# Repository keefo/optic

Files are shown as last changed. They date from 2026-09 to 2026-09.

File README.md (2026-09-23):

# Project Optic

Optic is an ultra-reliable, long-term timelapse system engineered around the Raspberry Pi 5 (1GB) and Raspberry Pi High Quality Camera, fitted with an official 6mm f/1.2 CS-mount wide-angle lens (PT361060M3MP12). Running on a stripped-down, headless Raspberry Pi OS Lite environment, Optic is architected for 365 days of unattended operation—pairing minimal memory overhead with a planned read-only root (OverlayFS, Phase 9; not yet enabled, see `docs/phase9-readonly-root.md`) to prevent file corruption across year-long captures.

## Specifications

### Compute & System
* **Host Platform:** Raspberry Pi 5
* **CPU:** Broadcom BCM2712 (Quad-core Arm Cortex-A76 @ 2.4GHz)
* **Memory:** 1 GB LPDDR4X-4267 SDRAM
* **Operating System:** Raspberry Pi OS Lite (64-bit, Debian base, headless)
* **Filesystem Architecture:** Writable ext4 root today, with RAM-backed `/mnt/capture` for capture staging; read-only OverlayFS root is planned (Phase 9, `docs/phase9-readonly-root.md`)

### Imaging & Optics
* **Sensor:** Raspberry Pi High Quality Camera (Sony IMX477)
* **Native Resolution:** 12.3 Megapixels (4056 × 3040 px)
* **Sensor Format:** 1/2.3" (7.9 mm diagonal, 1.55 µm × 1.55 µm pixel size)
* **Lens Mount:** CS-mount (with integrated back-focus adjustment ring)
* **Lens Model:** Official Raspberry Pi 6mm CS-Mount (`PT361060M3MP12` / `SC0124`)
* **Focal Length & Aperture:** 6.0 mm, adjustable f/1.2 – f/16
* **Field of View (FoV):** ~63° (horizontal)

### Enclosure
* **Design:** 3D-printable four-part outdoor box (base, lid, lens back, lens cover) — CAD source and print notes in [`case/`](case/README.md)
* **Format:** STEP AP214 assembly (`case/pi5/step/pi-cam-case-assembly.step`), editable in Fusion, FreeCAD, Onshape and other CAD tools
* **Licence:** CERN-OHL-S v2 (hardware design only; see `case/LICENSE-hardware.txt`)

### Networking & Access
* **Hostname:** `optic.local`
* **Remote Access:** OpenSSH (key-based authentication recommended)
* **Service Discovery:** mDNS / Avahi zero-configuration networking
* **Camera Dashboard:** [http://optic.local:8000/](http://optic.local:8000/)

## SSH Access

Connect over the local network via:

```bash
ssh liam@optic.local
```

## Hardening Verification

Run the read-only hardening verifier directly on `optic` without installing it:

```bash
cd /Users/admin/Documents/projects/optic
ssh liam@optic.local 'bash -s -- --color' < verify.sh
```

Results use green `PASS`, yellow `WARN`, red `FAIL`, and cyan `INFO` labels. Use `--no-color` for plain output. No settings are changed and no secret values are displayed.

Run one phase at a time with `--phase 1` through `--phase 9`. Phase 7 battery configuration is skipped on this deployment, Phase 8 commissions the HQ Camera, and Phase 9 (OverlayFS) is planned but not yet enabled. Reusable setup scripts are stored in `/Users/admin/Documents/projects/optic/scripts` where automation is appropriate.

## Camera Daemon

`optic-daemon` provides the camera dashboard, IMX477 status, validated camera controls, profile-aware MJPEG previews and test shots, and atomic publication to the Phase 6 RAM stage, plus the timelapse scheduler (`optic_scheduler`), in-process transfer to the iMac (`optic_sync`), capture history, and health alerts. The dashboard preview has browser-side focus tools (histogram, focus peaking, and a loupe with a sharpness score; `docs/optic-daemon-focus-tools.md`). Camera requests enter the bounded FIFO `optic_camera` actor and use one persistent native `libcamera` owner for preview and still capture. Master Archive previews at the full `4056 × 3040` resolution at 2 FPS; 4K DCI and 2K Binning use aspect-correct `1352 × 720` and `1014 × 760` previews at up to 8 FPS. Still captures remain Master Archive (`4056 × 3040`, JPEG Q100 + DNG), 4K DCI (`4056 × 2160`, JPEG Q95 with optional DNG), and 2K Binning (`2028 × 1520`, JPEG Q85). The native backend has been deployed since 0.1.3 (`worklogs/2026-09-16-native-camera-refactor.md`). It runs as the system service `optic-daemon.service` with `User=liam` (`docs/optic-daemon-system-service.md`) and is intentionally exposed on unprivileged TCP port `8000`; nothing listens on port `80`.

```bash
ssh liam@optic.local 'systemctl status optic-daemon.service'
curl http://optic.local:8000/healthz
```

Bootstrap the pinned Pi build environment, upload the current versioned source,
run all validation, build, install, and verify the deployment with one command
from the development Mac:

```bash
cd /Users/admin/Documents/projects/optic
./scripts/build-deploy-optic-daemon.sh
```

See [`optic-daemon.md`](optic-daemon.md) for the deployment procedure, API,
and live-validation record. See
[`optic-daemon-build-environment.md`](optic-daemon-build-environment.md) for
the pinned Raspberry Pi toolchain, native-library sysroot, exact build order,
and failure diagnosis.

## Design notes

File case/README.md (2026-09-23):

# Project Optic enclosure (Raspberry Pi 5 + HQ Camera)

3D-printable outdoor enclosure for the camera station described in the
[project README](../README.md): a Raspberry Pi 5, the Raspberry Pi High
Quality Camera (IMX477) and the 6 mm f/1.2 CS-mount lens
(PT361060M3MP12).

## Files

| Path | What it is |
| --- | --- |
| `pi5/step/pi-cam-case-assembly.step` | **The source model.** STEP AP214, exported from Fusion on 2026-09-22. One assembly holding all four parts as they fit together. Opens and edits in Fusion, FreeCAD, Onshape, SolidWorks and other CAD tools. |

The four parts in the assembly:

1. **Box base** – holds the Pi 5 and the camera module.
2. **Box lid** – closes the base.
3. **Lens back** – the lens mount behind the aperture.
4. **Lens cover** – the front cover over the lens.

> The bodies are unnamed inside the STEP file (the product name is the
> export timestamp), so other CAD tools show them as generic solids.
> Naming the components in Fusion before the next export would carry the
> names across.

### Not here yet

- **Per-part STEP files.** Exporting each component separately
  (right-click the component in the Fusion browser → *Save As STEP*, or
  export with only that component selected) produces one file per part.
  Using *File → Export* instead writes the whole design every time, which
  is why the first attempt produced four identical files.
- **Print-ready meshes** (`.3mf` preferred over `.stl`: it carries units,
  separate parts and print settings). Export each part laid flat in its
  print orientation, not in assembly position.
- **The Fusion source** (`.f3d`), which is the only format that keeps the
  parametric timeline.
- A dimensioned drawing (PDF) and a photo of the assembled box.

The earlier `RaspberryPi5caseV5T-*.stl` files were removed when this STEP
model replaced them: a mesh cannot be edited meaningfully, and those files
were a different design.

## Printing

Material: **ASA** — chosen for UV and heat resistance in a station meant to
run outdoors for a year. It needs an enclosed printer. PETG is a workable
substitute; PLA is not, since it sags in direct sun and goes brittle.

Everything below is still to be filled in from a real print:

| Setting | Value |
| --- | --- |
| Layer height | TBD |
| Wall loops / perimeters | TBD |
| Infill | TBD |
| Supports | TBD |
| Print orientation per part | TBD |
| Estimated print time / filament | TBD |

## Hardware (bill of materials)

TBD — screws, heat-set inserts, fan (the previous design used a 30 mm
fan), gasket or seal, and any lens-mount hardware.

## Assembly

TBD — the order the parts go together, where the cables run, and how the
camera ribbon is routed.

## Licence

The enclosure design in this directory is licensed under the **CERN Open
Hardware Licence Version 2 – Strongly Reciprocal** (`CERN-OHL-S-2.0`); see
[`LICENSE-hardware.txt`](LICENSE-hardware.txt). In short: you may use,
study, modify, make and distribute it, provided you pass on the same
freedoms and publish the source of any modified design you distribute.

This covers the hardware design files only. The software in this
repository is licensed separately.

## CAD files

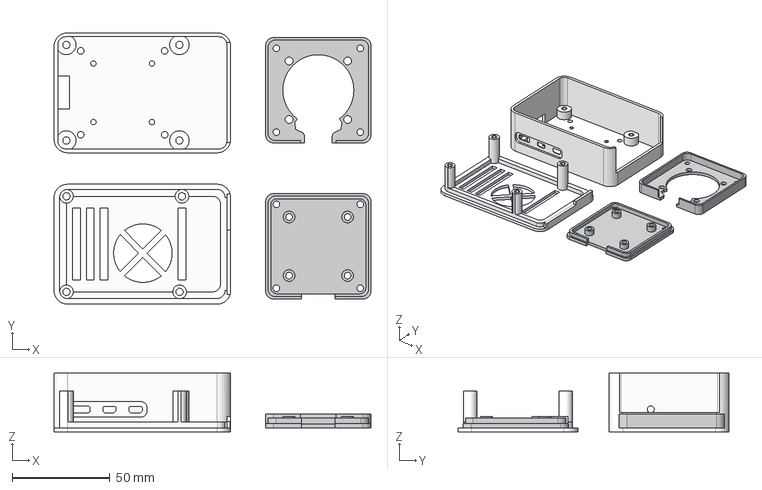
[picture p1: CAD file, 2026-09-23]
case/pi5/step/pi-cam-case-assembly.step
162.5 x 139.1 x 30.0 mm

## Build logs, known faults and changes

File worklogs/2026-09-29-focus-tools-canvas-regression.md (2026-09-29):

# Dated Worklog: 2026-09-29 - Focus Tools Silently Stopped Working After the Canvas Preview

Status: **implemented and locally tested**; Pi `--assets` deploy and user
acceptance pending.

## Objective

User report: Histogram, Peaking, Clipping and Loupe no longer do anything.
The buttons toggle, but nothing is drawn.

## Root Cause

A regression I introduced in PR #19. The iOS flicker fix replaced the
preview `<img id="preview">` with a `<canvas id="preview">`
(`worklogs/2026-09-28-ios-preview-stream.md`). `focus-tools.js` gained
`frameWidth()`/`frameHeight()` helpers for exactly this, and three call
sites were updated — but **`onFrame()` was missed**:

```js
if (!anyEnabled() || !img.naturalWidth || !img.naturalHeight) return;
```

`naturalWidth` is an `<img>` property; a `<canvas>` has `width`/`height`
and no `naturalWidth`. So the guard saw `undefined`, `onFrame()` returned
immediately on every frame, and all four tools did nothing. No error was
logged, because returning early is a legitimate path (it is how a
not-yet-loaded frame is skipped).

Why nothing caught it:

- The JS unit tests only covered the pure functions; the helpers lived
  inside the browser-only half of the file and were never exercised.
- The Rust asset tests pinned the canvas and `createImageBitmap`, not how
  the tools read the frame size.
- `worklogs/2026-09-28-ios-preview-stream.md` explicitly listed "focus tools
  not re-checked on a real device" as a remaining limitation. That gap is
  exactly where the defect sat.

## Fix

- `onFrame()` now reads the size through `frameWidth()`/`frameHeight()`.
- Those helpers moved from the browser-only half into the exported pure
  surface, so Node tests cover them.
- Tests:
  - `tests/web/focus-tools.test.js`: a canvas-shaped object, an image-shaped
    object (intrinsic size beats layout size), and not-ready sources
    returning 0.
  - `src/web.rs`: asserts `onFrame` uses `frameWidth(img)` and that the only
    `.naturalWidth`/`.naturalHeight` reads in the file are the helpers.

## Validation (local, macOS)

| # | Check | Result |
|---|---|---|
| 1 | `node --test tests/web/*.test.js` | **31 passed** (4 new assertions) |
| 2 | `cargo test --locked` | **280 passed** |
| 3 | Mutation check: reintroduce `img.naturalWidth` in `onFrame` and re-run | the new Rust test **fails**, so the guard is real |
| 4 | Biome 2.5.14 on `focus-tools.js` | clean |
| 5 | Pi deploy (`--assets`) | pending |
| 6 | User acceptance: all four tools on a device | pending |

## Remaining Limitations / Follow-up

- Still no automated test that exercises the tools against a real rendered
  frame; they are verified by unit tests plus a human clicking. A headless
  browser check would close this properly.
- The same class of bug could exist wherever other code assumes the preview
  is an `<img>`. `app.js` and `scheduled-exposure.js` were grepped for
  `naturalWidth`/`naturalHeight` and are clean.

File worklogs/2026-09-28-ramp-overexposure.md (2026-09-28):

# Dated Worklog: 2026-09-28 - AutoRamp Overexposed Frame at Dawn (08:00)

**Status:** cause identified and replayed offline; fix **implemented and
unit-tested on the Mac**. **Not compiled for Linux, not deployed, not
hardware-validated, not user-accepted.** (Investigation, acceptance
criteria and test plan were written before any `src/` change.)

## Objective

One scheduled capture came out white:
`scheduler-master-archive-everyhour-1790607601441.jpg` (2026-09-28 08:00:01
PDT, rule `everyhour`, `AutoRamp`). Find out why, fix it, and make any future
failure like it obvious in the logs.

## Evidence (read-only; gathered 2026-09-28)

Sources: the sidecar in `~/Pictures/Optic` (read only), the Pi's
`/api/status`, `/api/captures` and `journalctl -u optic-daemon` (read-only
SSH).

| What | Value |
|---|---|
| Rule | `everyhour`: interval 3600 s aligned to the wall clock, window 08:00–21:00 every day |
| Station | 49.2236 N, −123.0009 E, America/Vancouver |
| Sun at 08:00:00 PDT | +7.6° (above the +6° day threshold, so the target is the day level) |
| 08:00 requested (`settings`, i.e. the built `CaptureRequest`) | `shutter_us: 343529`, `gain: 1.0` |
| 08:00 actual | 342,916 µs, gain 1.0; meter L = 0.807, clipped 60.1% |
| Warmup frames | 2, both already at 342,916 µs (manual-match early exit) |
| Previous scheduled captures | a 1-minute rule until 00:58:09 PDT, last at 4,227,272 µs × 1.12 gain |
| Daemon restarts | 01:10:36 → 01:13:39 and 01:27:29 → **01:31:00 PDT** (ramp state is in memory, so it was reset to `None`) |
| Live preview | pipeline **started at 01:31:26 PDT and ran without a stop until 08:00:00**, when the scheduled capture's `stop_existing_preview` stopped it |
| Afterwards | 09:00–11:00 captures in `Dashboard` mode, `shutter 0` (auto) × gain 11.5: 552–635 µs × 11.38 |

Correction to the brief: "correct exposure was about 0.6 ms" leaves out the
11.38× gain. The 09:00 dashboard frame is 635 µs × 11.38 ≈ **7.2 ms at gain 1**,
so 343 ms at gain 1 was about **5.6 EV** over the dashboard frame an hour
later, not 9 stops. At 07:59 on 2026-09-25 (sun +8°), the ramp's mid-grey
exposure was at most 53 ms, which puts 343 ms about 2.7 EV over.

## Which code path ran

**It was a `Manual` plan, not a seed.** `build_capture_request` writes
`shutter_us = 0, gain = 0` for `RampPlan::Seed`, and the sidecar's `settings`
is that request. A seed would also have run all 11 warmup frames, because
`capture_this_frame` never exits early for auto exposure. The 08:00 capture
requested 343,529 µs × 1.0 and stopped at frame 2 on a manual match.

**Where 343,529 µs comes from.** After the 01:31 restart the ramp had no
state. No scheduled capture ran between 01:31 and 08:00: the 1-minute rule
had ended and `everyhour`'s window opens at 08:00. So every bit of ramp state
at 08:00 came from `observe_preview`:

- `observe_preview` with no state creates one with
  `planned_log2_exposure: None`, so the next capture plan has **no step
  limit**.
- Every preview frame sets `updated_at = now`, so `plan()`'s
  `now − updated_at ≤ 30 min` check passed at 08:00 even though no frame
  had been captured for 7 hours.
- In `AutoRamp` the preview runs the dashboard's `exposure_override`, and
  `previewEquivalent` clamps that to one frame time (118,750 µs at 8 fps × 0.95)
  and at most 16× gain. The night plan (~4.2 s × 1.1–1.3) sits at that cap:
  118,750 × 16 = 1.90e6 µs·gain.
- As the sky brightened, preview frames at that fixed exposure turned white.
  A saturated frame's trimmed log-mean is `linear(255)` = 1.0043, so the
  "scene" sample is `log2(1.0043) − log2(1.90e6)` ≈ −20.85. That is only a
  **lower bound** on the scene's brightness, but the estimate took it as a
  measurement and converged to it (5 s time constant).
- `plan` = `log2(0.18) − (−20.85)` = **18.39 → 2^18.39 ≈ 343 ms at gain 1**
  (shutter-first below the 5 s cap).

The prediction `0.18 × 118,750 × 16 / 1.0043` = 340.5 ms is within 1% of the
343,529 µs requested. The remaining 0.9% is the sensor's line quantisation of
the preview exposure, the same order as the +1.0% recorded in `camera.rs`.
Replayed in the unit test `replay_2026_09_28_dawn_overexposure` (below).

For the preview exposure to stay at the 16× cap through dawn, the client
holding the stream cannot have been sending new overrides. A live dashboard
would have followed the falling plan down: 343 ms plan → 118,750 µs × 2.9.
Which client held the stream (for example a backgrounded tab or a locked
phone) cannot be told from the logs.

### Verdict on the three hypotheses in the brief

1. **Reseed did not fire because preview activity keeps the state fresh:
   supported.** This is the enabling cause. The only reseed check is
   `now − updated_at`, and `observe_preview` refreshes `updated_at` at frame
   rate. The state was never anchored to a capture.
2. **Seed ran but auto exposure did not converge in 2 warmup frames:
   refuted for this incident.** The frame was a manual plan (see above). A
   seed keeps all 11 frames. On 2026-09-28 01:17, a dashboard auto-exposure
   capture was still moving about 0.2 EV between frames 9 and 11, so AE is
   roughly but not exactly converged by frame 11. That is not what happened here.
3. **Scene estimate learned from preview frames exposed by something other
   than the ramp: supported, and made more precise.** The estimate came from
   preview frames **saturated** at the preview override's 16× ceiling. A
   saturated meter is a lower bound, and with no capture anchor the plan
   jumped to it with no step limit.

The ramp logged nothing about the decision (only `highlight guard darkened the
ramp` exists), so this was proven from arithmetic and timelines, not from a
log line. Fixing that is part of this work.

## Clamp data (for the sanity bound)

Mid-grey exposure product `0.18 / 2^(log2 L − log2(µs × gain))`, over 2,269
scheduler frames with a usable meter (0.005 < L < 0.5), grouped by sun
elevation computed for the station. Only two dawns and dusks
(2026-09-24/25) cover the horizon:

| Sun | max mid-grey exposure (gain 1) |
|---|---|
| 0…+1° | 621 ms |
| +1…+2° | 390 ms |
| +2…+3° | 283 ms |
| +3…+4° | 154 ms |
| +4…+6° | 109 ms |
| +6…+7° | 79 ms |
| +7…+9° | 53 ms |
| ≥ +10° | ≤ 41 ms |

**This contradicts the brief's "sun above the horizon → refuse multi-hundred-ms
exposures".** On this station, 300–600 ms is normal with the sun at 0–2°, so a
flat sub-100 ms bound would clip real dawns. The bound has to follow
elevation. Proposal, subject to the user's decision (asked with the question
tool):

```
ceiling(el) = max(160 ms, 2.5 s · 2^(−el / 2)) · 2^day_bias_ev   for el ≥ 0°
no ceiling below the horizon or without a station
```

Measured frame by frame at each frame's own elevation, it is at least **1.6 EV**
above every observed mid-grey exposure (tightest: 52.8 ms at +8.2°). (An
earlier draft of this line said "≥ 2 EV" from bin edges. The unit test caught
it: 1.98 EV at +6°, and 1.6 EV per frame. The user-approved formula is
unchanged; the justification is corrected.) At +7.6° it is 180 ms, so on its own it
would have cut the incident by about 0.9 EV, not prevented it. It is a
backstop. The reseed rule is the fix.

## Acceptance criteria

A1. A `RampState` that has not learned from a **scheduled capture** within
    `RESEED_GAP` plans a `Seed` for the next capture, however recently preview
    frames updated it. The dashboard's live plan and preview override keep
    working from preview-learned state (§11 behaviour unchanged).
A2. Replaying the 2026-09-28 sequence (night captures, restart, 6.5 h of
    preview frames at 118,750 µs × 16 that saturate at dawn, hourly capture at
    +7.6°) plans ≈ 343 ms on the old rule (proves the cause) and a `Seed` on
    the new one.
A3. Every scheduled `AutoRamp` capture logs one INFO line with the decision:
    `seed` or `plan`, the reason for a seed (no state, no capture yet, gap),
    the age of the last capture, scene estimate, sun elevation, target bias,
    desired and planned log2 exposure, whether the step limit and the daylight
    ceiling bound it, the guard offset, the last frame's clipped fraction, and
    the resulting shutter/gain. Every observed result logs one INFO line too.
    A plan cut by the daylight ceiling logs a WARN.
A4. Daylight sanity ceiling (bound as decided by the user) applies to capture
    plans and preview plans alike, never below the horizon or without a
    station, and never brightens a plan.
A5. Existing ramp behaviour and tests are unchanged apart from these rules:
    step limits, guard, preview learning, interval budget.
A6. `cargo fmt --check`, `cargo test --locked`,
    `cargo clippy --locked --all-targets -- -D warnings` pass on the Mac.
A7. `docs/optic-daemon-exposure-ramping.md` describes the new reseed rule, the
    ceiling and the logging; this worklog records results.

## Decisions (user, 2026-09-28, via the question tool)

| Question | Answer |
|---|---|
| Sanity ceiling | **Elevation curve**: `max(160 ms, 2.5 s · 2^(−el/2)) · 2^day_bias_ev`, sun ≥ 0° only, WARN when it binds |
| Meter-then-shoot for long gaps | **Implement now** |
| Time-based step limit | **Implement now**: `max_step_ev × max(1, minutes since the last capture)` |

Added acceptance criteria:

A8. **Meter-then-shoot.** When a scheduled `AutoRamp` shot's plan is a seed
    (no capture within `RESEED_GAP`), the scheduler first takes an unsaved
    auto-exposure metering still (`OpticCamera::meter`: same pipeline and
    warmup as a seed still, no JPEG/DNG encode, no file, no capture-history
    row), folds it in as a seed, re-plans, and shoots the resulting manual
    plan. The target curve and ceiling therefore apply to long-gap shots too.
    If metering fails, it falls back to the old behaviour (the seed still is
    the output frame) with a WARN.
A9. **Time-based step limit.** The per-plan step limit is
    `max_step_ev × max(1, minutes since the anchoring capture)`, in both
    directions. The guard's extra downward allowance is unchanged. 1-minute
    and faster rules behave exactly as before.
A10. A ramped output frame with ≥ 25% of samples clipped logs a WARN
    (`ramped capture is overexposed`). `/api/status` → `schedule.exposure` also
    reports whether a metering pass ran, whether the ceiling bound, and the
    clipped fraction.

Added tests:

- `meter_then_shoot_plans_the_target_from_the_metering_frame`: a seed
  observation of an AE dawn frame followed by a re-plan gives a manual plan
  at the day target, and within the ceiling.
- `step_limit_scales_with_minutes_since_the_capture`: 1 min → 1 step; 10 min
  → 10 steps; 30 s → still 1 step.
- The replay test, after the fix: capture plan `Seed`; after a metering
  frame at the real dawn scene, the plan is within 0.1 EV of the day target
  (≈ 45 ms), not 343 ms.

Scope note: meter-then-shoot needs a small addition outside the files this
track owns: a `Meter` command in `src/optic_camera.rs` and the Linux/stub
backends in `src/native_camera.rs`. It reuses the existing `capture_frame`
(warmup, AE) and `meter_yuv420` unchanged.

## Test plan (written before implementation)

Host unit tests in `src/exposure_ramp.rs` (`cargo test --locked`, Mac):

- `replay_2026_09_28_dawn_overexposure`: builds the state as the Pi did
  (preview-born state, preview frames at 118,750 µs × 16 from 01:31 with a
  night scene, then a dawn scene that saturates them, i.e. meter
  L = 1.0043 / clipped ≈ 1.0). On the **pre-fix** rule it asserts a
  `Manual` plan of 343 ms ± 2% at gain 1 (proof); after the fix the same
  replay asserts `Seed`. Written first and run against unmodified code to
  show the old path.
- `preview_activity_does_not_keep_a_stale_capture_state_fresh`: captured
  state at T, preview frames every few seconds for 2 h, plan at T+2 h → Seed
  (fails today: today it plans `Manual`).
- `preview_only_state_seeds_the_capture_but_still_drives_the_preview`: state
  created by preview only → capture plan `Seed`; `preview_plans` still
  `Some` (§11 kept).
- `a_recent_capture_keeps_planning_with_preview_updates`: capture at T,
  preview frames, plan at T+10 min → `Manual`, step-limited from the capture.
- Ceiling tests: at +7.6° the plan is ≤ ceiling; below 0° and without a
  station no ceiling applies; the ceiling never brightens; `day_bias_ev`
  shifts it.
- `decision` tests: the decision struct reports reason/step-limit/ceiling
  flags that match the plan.

Scheduler (`src/optic_scheduler.rs` tests): `live_exposure_plan` still shows
a manual preview plan for preview-only state and reports that the next capture
seeds.

Failure cases covered: no state; preview-only state; stale capture with fresh
preview; fresh capture; saturated preview frames; no station.

Target environment for real validation: the Pi (needs user approval to
deploy), across a dawn with an hourly rule in `AutoRamp`, compared against the
numbers above. Not part of this session unless approved.

## Implementation (2026-09-28)

- `src/exposure_ramp.rs`
  - `RampState.captured_at`: set by `observe` (captures and metering
    passes), carried by `observe_preview`, `None` for preview-born state.
  - `decide()` → `RampDecision` (plan, `SeedReason`, capture age, scene,
    sun, target, desired E, step limit and whether it bound, ceiling and
    whether it bound, guard offset and previous excess, max shutter).
    `plan()` = `decide().plan`. Capture freshness: a capture within
    `RESEED_GAP`, otherwise `no_state` / `no_capture` / `capture_gap`.
  - `preview_plan()`: the old `updated_at` freshness, used only by
    `preview_plans` and the live plan (§11 preview behaviour unchanged).
  - `step_limit_ev()`: `max_step_ev × max(1, minutes since the capture)`.
  - `daylight_ceiling_log2()`, applied in `ExposureLimits::split` (capture
    and preview plans). The guard's `E_max` is unchanged.
  - `OVEREXPOSED_CLIPPED_FRACTION = 0.25`.
- `src/optic_scheduler.rs`: `RampShot` carries the decision;
  `fire_capture` logs every decision, runs `meter_then_plan` for seeds
  (unsaved metering still → `observe` as seed → re-plan → manual shot; on
  failure WARN and shoot the seed), and logs every observation plus the
  overexposure WARN. `LiveExposurePlan` gains `ramp_captured_at` and
  `capture_meters_first`; `RampSnapshot` gains `metered`, `seed_reason`,
  `ceiling_bound`, `clipped_fraction` (all additive JSON).
- `src/optic_camera.rs`: `CameraCommand::Meter` / `OpticCamera::meter`.
- `src/native_camera.rs`: `NativeCommand::Meter` (Linux: stop preview,
  `capture_frame` + `meter_yuv420`, no encode or write, `metering_pass`
  perf log); stub returns `Unavailable`. Warmup count and `set_controls`
  unchanged: the seed path's AE behaviour is the existing 11-frame still.
- `docs/optic-daemon-exposure-ramping.md`: status line, §5.3 time-based
  step, §5.4 rewritten (capture-anchored reseed, incident, meter-then-shoot),
  new §5.8 ceiling and §5.9 logging, §8 failure rows, §9 follow-ups, §11
  "starts from a converged estimate" withdrawn.
- No JS/UI change, no dependency or version change (0.1.33; the bump happens
  at merge).

## Validation (Mac, 2026-09-28)

| Check | Result |
|---|---|
| `cargo test --locked replay_2026_09_28` on **unmodified** code | passed: preview-only state, saturated dawn frames → `Manual` plan within 2% of 343,529 µs at gain 1.0 (reproduces the incident) |
| `cargo test --locked` after the core change, before updating old tests | 271 passed, 2 failed: exactly the two tests encoding the old rule (`replay_2026_09_28_dawn_overexposure` asserting `Manual`, `a_preview_seeded_ramp_plans_without_a_step_limit`) |
| `cargo test --locked` (final) | **279 passed, 0 failed** (273 before: +6 new tests, 2 rewritten, 1 scheduler test extended) |
| `cargo fmt --check` | passed |
| `cargo clippy --locked --all-targets -- -D warnings` | passed (Mac target) |
| Linux/aarch64 compile of `native_camera.rs` `Meter` arm | **not run.** The `vmpi` VM is stopped and lacks the RPi `libcamera-dev` 0.7.2+rpt; compiling on the Pi is not read-only. It mirrors the existing `Capture` arm's calls and was reviewed by hand. CI's `rust-arm64` job will compile it on the first push. |

Regression tests (fail on the old behaviour, pass now):
`replay_2026_09_28_dawn_overexposure` (old path 343 ms; ceiling alone 180 ms;
now `Seed/no_capture`, then a metering frame → plan within 0.1 EV of the 45 ms
day target), `preview_activity_does_not_keep_a_stale_capture_state_fresh`,
`a_preview_seeded_ramp_previews_without_a_step_limit_but_captures_meter_first`,
`a_recent_capture_keeps_planning_through_preview_updates` (10 min → 10 steps),
`step_limit_scales_with_minutes_since_the_capture`, `seeds_report_why`,
`daylight_ceiling_follows_the_sun`, `daylight_ceiling_only_ever_darkens_a_plan`,
and `live_exposure_plan_seeds_without_state_and_tracks_the_ramp_with_it`
(extended: `capture_meters_first`).

Review fix: after a metering pass, the snapshot's `seed_reason` was
overwritten by the re-plan. It now keeps the original reason.

## Limitations and risks

- Unverified on Linux and on hardware. The metering pass's timing and AE
  convergence (11 frames, 500 ms frame cap at night) are unmeasured. At
  night AE may meter dark, but the estimate is normalised by the actual
  exposure, so it stays correct unless the frame is crushed.
- A metering pass delays the output frame by one still: about 1 s by day,
  more at night. Only long-gap shots pay it.
- The ceiling comes from one station and two mornings (1.6 EV minimum
  margin). A very dark day could reach it; the WARN makes that visible.
- Preview learning still treats saturated frames as measurements. Captures
  no longer plan from preview-only state, but the preview's own plan can
  still sit on that bound when no client re-sends the override (UI
  follow-up). Which client held the stream overnight is unknown.
- WARNs go to the journal and `/api/status` only, not to system events or
  ntfy alerts (needs `main.rs` wiring; follow-up).
- The 30-minute `RESEED_GAP` is unchanged. With the time-based step, a rule
  every 10–30 min may now move up to 10–30 steps between frames.

## Proposed validation on the Pi (needs user approval)

1. Merge with the version bump (0.1.34), then deploy it with the existing
   script. Leave `Dashboard` mode on until deployed.
2. Before a dawn, switch `schedule.exposure` to `AutoRamp` (defaults) with
   the hourly `everyhour` rule, and optionally a 10-minute rule across
   06:30–09:00.
3. Watch `journalctl -u optic-daemon | grep -E "exposure ramp|metering_pass|overexposed|daylight ceiling"`.
   Expected at 08:00: a `seed_reason=no_capture` or `capture_gap` decision,
   a `metering_pass`, a second decision `plan` with `ceiling_bound=false`,
   and a frame of about 30–60 ms at gain 1 (compare: 343 ms / 60% clipped
   on 2026-09-28; 7.2 ms-equivalent dashboard frames at 09:00). No
   `overexposed` WARN.
4. Compare sidecars: `clipped_fraction` < 0.1 and YAVG not near 255.
5. Deliberately leave a preview open overnight, as on 2026-09-28, to confirm
   the dawn capture still meters first.

## User verification

After deploy: confirm the dawn frames look right, and that the dashboard
preview still shows the ramp plan before the first capture.

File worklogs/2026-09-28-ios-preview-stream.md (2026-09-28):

# Dated Worklog: 2026-09-28 - Live Preview Fails on iOS Safari ("load failed")

Status: **implemented, deployed (0.1.32 + assets), and user-verified on iOS**
(flashing confirmed gone by the user; layout change awaiting their comment).

## Objective

The dashboard's live preview does not work on iOS Safari. The page shows
"Preview stream interrupted: Load failed". Every other page and API call
works on the same device. Chrome on the Mac works fine against the same
daemon, through the same Tailscale proxy.

## Evidence (collected before any change)

From the Mac-side reverse proxy's access log
(`~/Library/Logs/optic-proxy.log`, Caddy JSON), same daemon, same URL:

| Client | `GET /api/stream/mjpeg` | Bytes delivered |
| --- | --- | --- |
| Chrome / curl (Mac) | 200 | 73,841 then 4,499,493 |
| iPhone, iOS 18.7 Safari | 200 (x6 retries) | **0**, request ends immediately |

So the response headers arrive, the body delivers nothing, and the fetch
fails. "Load failed" is Safari's generic `TypeError` for a failed fetch.
The retries are `consumeMjpeg`'s own reconnect path in `app.js`.

## Root cause (hypothesis to confirm with the fix)

`app.js` does not use `<img src=...>` for the preview. It calls
`fetch('/api/stream/mjpeg')` and parses the multipart framing itself, so it
can read the per-frame `X-Optic-*` headers (sequence, exposure, gain,
clipped fraction) that the responsiveness panel and the ramp UI display.

WebKit handles `multipart/x-mixed-replace` inside its network layer — the
legacy "server push replace" mechanism it implements for `<img>`. A
`fetch()` of such a response does not hand the parts to JavaScript;
WebKit consumes them, so `response.body` yields nothing and the fetch
fails. Chromium has no such interception, which is why Chrome works.

The framing bytes are identical either way. Only the `Content-Type` makes
WebKit intercept.

## Approach

Let the caller ask for the same byte stream under a neutral media type:

- `GET /api/stream/mjpeg` keeps `multipart/x-mixed-replace; boundary=frame`
  (unchanged, still valid for direct `<img>` use, as `docs/optic-daemon.md`
  documents).
- `GET /api/stream/mjpeg?parser=js` returns exactly the same bytes with
  `Content-Type: application/octet-stream`, which WebKit does not
  intercept.
- `app.js` requests the `parser=js` form, since it always parses the
  stream itself.

This keeps one server code path and one client parser. It is not an
iOS-specific branch: every browser gets the non-intercepted type.

## Acceptance Criteria

1. The live preview runs on iOS Safari: frames paint, and the stream is
   not interrupted.
2. Chrome and Safari on macOS still work, with the responsiveness panel,
   the focus tools and the ramp readouts unchanged (they depend on the
   per-frame headers, which the framing still carries).
3. `GET /api/stream/mjpeg` without the query parameter still returns
   `multipart/x-mixed-replace`, so a direct `<img>` still works.
4. No change to frame content, framing, headers or cadence.

## Test Plan (written before implementation)

Local (macOS):

1. New `web.rs` unit tests: the default request keeps
   `multipart/x-mixed-replace; boundary=frame`; `?parser=js` returns
   `application/octet-stream`; both keep the no-store headers. An asset
   test asserts `app.js` requests the `parser=js` form.
2. `cargo fmt --check`, `cargo test --locked`, `cargo clippy --locked
   --all-targets -- -D warnings`.
3. Biome on the changed web assets.

On the Pi (needs user approval; this is a Rust change, so a full deploy
with a version bump at merge):

4. `curl -sI 'http://optic.local:8000/api/stream/mjpeg'` → multipart;
   `curl -sI '...?parser=js'` → application/octet-stream.
5. Confirm bytes still flow: read the first part header from the
   `parser=js` form and check it contains `X-Optic-Sequence`.
6. **User verification on the iPhone** (the actual acceptance): open the
   dashboard over the tailnet, confirm the preview paints and no
   "interrupted" notice appears. Then re-check Chrome on the Mac.

## Second Defect Found After the Fix: Flashing on iOS

With the stream working, the preview flashed black 2-3 times a second on
iOS Safari (not on Chrome/macOS). Cause: `app.js` rendered each frame by
assigning a blob URL to `<img id="preview">.src` and awaiting `decode()`.
WebKit blanks an image element as soon as `src` changes and only paints
once the new frame has decoded, so every frame left a visible gap. Chromium
keeps the previous frame on screen during the decode, which is why the Mac
looked fine.

Fix: the preview is now a `<canvas>`. Each frame is decoded with
`createImageBitmap()` and drawn with `drawImage()`, so the previous frame's
pixels stay until the next draw and there is no blank state. It also
removes the per-frame `createObjectURL`/`revokeObjectURL` pair.

## Third Change (user request, same session)

The status line (`#stream-state`, e.g. "Live · 4056 × 3040 · 2 FPS · White
balance Daylight · … · Analogue gain 11.5×") sat above the preview and
re-wrapped whenever a control changed, pushing the image down the page. It
now sits **below the preview frame and below the Capture/Stop buttons**,
with a reserved `min-height` so one- and two-line states do not move
anything.

## Implementation Summary

- `src/web.rs`: `MjpegParams { parser }`, `mjpeg_content_type()`, and
  `mjpeg_stream` takes `Query<MjpegParams>`. Default stays
  `multipart/x-mixed-replace; boundary=frame`; `?parser=js` returns
  `application/octet-stream`. Same bytes either way.
- `src/web/app.js`: requests `?parser=js`; renders through
  `createImageBitmap` + `drawPreviewFrame()` into the canvas;
  `clearPreviewCanvas()` replaces `removeAttribute("src")`; the `<img>`
  `error` listener and all blob-URL handling are gone.
- `src/web/index.html`: `<img id="preview">` → `<canvas id="preview"
  role="img" aria-label="HQ Camera preview">`; `#stream-state` moved out of
  the section heading to below the button row.
- `src/web/focus-tools.js`: `frameWidth()`/`frameHeight()` helpers, so the
  tools read the intrinsic size of either a canvas or an image.
- `src/web/styles.css`: the preview box rules apply to the canvas;
  `#stream-state` restyled for its new position.
- `docs/optic-daemon.md`: the `/api/stream/mjpeg` entry documents `?parser=js`
  and why it exists.
- `Cargo.toml`/`Cargo.lock`: `0.1.31` → `0.1.32` (this deploy also carried
  the six PRs merged since 0.1.31 to the Pi for the first time).

## Validation

| # | Check | Environment | Result |
|---|---|---|---|
| 1 | `cargo test --locked` | macOS | **271 passed**, including the three new tests |
| 2 | `cargo clippy --locked --all-targets -- -D warnings` | macOS | clean |
| 3 | `cargo fmt --check` | macOS | clean |
| 4 | Biome 2.5.14 on the changed web assets | macOS | clean |
| 5 | `node --test tests/web/*.test.js` | macOS | pass |
| 6 | Full deploy | Pi | **265 tests passed on the Pi**, `SUCCESS: optic-daemon 0.1.32 is active` |
| 7 | Content types on the Pi, with a preview running | Pi | default → `multipart/x-mixed-replace; boundary=frame`; `?parser=js` → `application/octet-stream`, 8,550,394 bytes in ~5 s, framing and `X-Optic-Sequence` intact |
| 8 | `--assets` deploy of the canvas + layout change | Pi | `SUCCESS`; served page contains `<canvas id="preview"`, `app.js` contains `createImageBitmap`, `#stream-state` follows `#preview-toggle` |
| 9 | **iOS Safari 18.7** | iPhone, over the tailnet proxy | Preview renders, and the user confirmed the **flashing is gone** |

Diagnosis evidence for #9's root cause is in "Evidence" above: the Caddy
access log showed the iPhone receiving 0 bytes on six MJPEG attempts while
the Mac received 73 KB and 4.5 MB on the same endpoint.

## Remaining Limitations / Follow-up

- The user has not yet commented on the moved status line; that part is
  deployed but not confirmed.
- The `<img>`-only path (`/api/stream/mjpeg` without `parser=js`) is no
  longer exercised by any page. It is kept because `docs/optic-daemon.md`
  documents it for direct `<img>` use, and a unit test pins the content
  type.
- Not re-checked after the canvas change: the focus tools (histogram,
  peaking, clipping, loupe) on a real device. Their size lookups changed,
  their unit tests pass, but nobody has clicked through them since.
- The responsiveness panel's "first visible" timing now measures canvas
  draw plus two animation frames rather than `<img>` decode plus paint.
  Numbers before and after this change are not directly comparable.

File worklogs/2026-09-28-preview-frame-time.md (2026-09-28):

# Dated Worklog: 2026-09-28 - Show the Pi-Side Capture Time on the Live Preview

Status: **implemented and locally tested**; Pi deploy and user acceptance pending.

## Objective

User request: show, in the top-right of the live preview, the time the Pi
took the frame being displayed, so it is obvious how fresh the image is.
Preview only — scheduled captures must not be overlaid or otherwise changed.

## Design

- `PreviewFrame` gains `captured_at: Option<SystemTime>`, stamped in
  `native_camera.rs` at the moment the frame is encoded and published.
- `mjpeg_part` sends it as `X-Optic-Captured-At`, epoch milliseconds, beside
  the existing per-frame `X-Optic-*` headers. `unavailable` when absent, like
  the other optional headers.
- `app.js` reads the header on each painted frame and renders it into a new
  `#frame-time` overlay, formatted with `Intl.DateTimeFormat` in the
  **station timezone** from `/api/status`
  (`config.schedule.station.timezone`, e.g. `America/Vancouver`), not the
  viewer's. A phone in another timezone, or with a clock that differs from
  the Pi's, still shows the Pi's time.
- The label hides when the preview stops and when a frame carries no
  timestamp.

Captures are untouched: no pixels are drawn into any frame, and the overlay
is a DOM element over the preview canvas, so scheduled shots and their
EXIF/sidecar data are unaffected.

## Acceptance Criteria

1. The live preview shows the frame's capture time, top-right, updating with
   the stream.
2. The time is the Pi's, in the station timezone, regardless of the viewing
   device's clock or zone.
3. Scheduled captures are unchanged: no overlay, no new file content.
4. The label disappears when the preview is stopped.
5. It never blocks the loupe or the focus-tool overlays (`pointer-events: none`).

## Test Plan (before implementation)

1. `cargo test --locked`: `mjpeg_part` emits `X-Optic-Captured-At` with epoch
   milliseconds, and `unavailable` when the frame has no timestamp; asset
   tests pin `#frame-time`, the header name, `stationTimezone` and the render
   call in `app.js`.
2. `cargo clippy`, `cargo fmt`, Biome on the changed assets.
3. On the Pi (needs approval): confirm a live stream part contains
   `X-Optic-Captured-At` with a plausible epoch, and that the value tracks
   the Pi's clock.
4. **User acceptance:** the label appears, reads the Pi's local time, and a
   scheduled capture is unaffected.

## Implementation Summary

- `src/camera.rs`: `PreviewFrame.captured_at`.
- `src/native_camera.rs`: stamped with `SystemTime::now()` at publish.
- `src/web.rs`: `X-Optic-Captured-At` header; tests extended.
- `src/web/index.html`, `styles.css`: the `#frame-time` overlay.
- `src/web/app.js`: `renderFrameTime()`, the cached `Intl.DateTimeFormat`
  keyed on the station timezone, and `stationTimezone` learned from
  `/api/status`.
- `Cargo.toml`/`Cargo.lock`: `0.1.32` → `0.1.33` (0.1.32 is already deployed).

## Validation (local, macOS)

| # | Check | Result |
|---|---|---|
| 1 | `cargo test --locked` | **272 passed** (2 new assertions + 1 new test) |
| 2 | `cargo clippy --locked --all-targets -- -D warnings` | clean |
| 3 | `cargo fmt` | clean |
| 4 | Biome 2.5.14 on `app.js`, `index.html`, `styles.css` | clean (one formatting fix applied) |
| 5 | Pi deploy | **pending** |
| 6 | User acceptance | **pending** |

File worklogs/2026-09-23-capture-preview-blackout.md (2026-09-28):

# Dated Worklog: 2026-09-23 - Preview Blackout During Scheduled Captures

Status: **implemented, compiled and tested on the Pi (Linux gates), deployed
(branch build, still 0.1.31), and hardware-validated for B1/B4/B5; B3 not
compared; not user-accepted.** The test plan was written before any `src/` edit.

## Objective

User: "preview frame rate should be consistent." At night, with a scheduled
capture every minute, the live preview is live for only about half of each minute.
Shorten the blackout that each scheduled capture causes, without changing what
the capture records.

Context: found while verifying the Scheduled exposure preview fix
(`worklogs/2026-09-23-highlight-guard.md`, Part 3). Built on branch
`highlight-guard` (PR #18) at the user's request ("commit + push, then fix
frame rate").

## Evidence (Pi, 2026-09-23 23:53–23:56 PDT, read-only journal and a stream recording)

A scheduled capture runs `stop_existing_preview`, starts a still pipeline, and
waits `request_count (3) + CAPTURE_WARMUP_FRAMES (8)` = 11 frames. Then
the preview restarts. Per-frame `warmup_frame` trace of the 23:54 capture
(planned 3,440,629 µs × 1.0):

| Frame | exposure_us | gain | frame_duration_us | colour gains |
|---|---|---|---|---|
| 1–3 | 118,745 (the preview's) | 12.19 | 124,990 | 3.24015 → 3.24054 |
| 4 | 118,745 (the preview's) | 12.19 | 1,737,437 | 3.24072 |
| 5–11 | 3,474,267 (the still's) | 1.0 | 3,474,875 | 3.24089 → 3.23804 |

- New controls take effect from frame 5; frame 4 is transitional. This matches
  `docs/optic-daemon-capture-performance.md` §7 ("new request controls apply
  from frame 4") and its open follow-up: "pass the still limits to
  `camera.start()`".
- Colour gains move < 0.1% across all 11 frames (AWB preset Daylight). The
  captures at 23:55 and 23:56 look the same.
- `warmup_and_capture` took 25,072 ms, 22,758 ms and 10,952 ms (night
  frames of 3.47 s, 3.13 s and 1.46 s). Frames 6–11 are copies of frame 5 that
  cost 6 × the exposure: about 21 s at 3.5 s.
- After the capture, the preview restarts, and its first frames carry the still's
  exposure (the recording: 2 frames at 3,474,267 µs × 1.0, sequence 0–1), so there
  are about 7 more seconds at about 0.3 fps.
- An exposure change on a running preview is controls-only
  (`ReconfigureStream`: no pipeline restart). The blackout comes only from
  captures.

## Design

1. **A manual still captures the first frame that really has the requested
   exposure.** When the still request has a manual shutter and gain (both > 0,
   as every ramped frame does), the capture loop takes the first completed frame
   whose metadata `ExposureTime` and `AnalogueGain` are within 5% of the
   request (the sensor quantises: 3,440,629 requested gave 3,474,267, +1.0%)
   and whose colour gains are within 1% of the previous frame's (AWB settled;
   covers AWB Auto). If no frame qualifies by today's frame 11, it takes frame
   11 as today, and warns. Stills with auto shutter or gain keep today's
   11 frames.
2. **Pipelines start with their own controls.** `start_pipeline` passes the
   same controls it puts on each request to `camera.start(Some(&controls))`.
   The first frames after a capture should then use the preview's exposure
   (removing the slow tail), and a manual still's exposure should apply from frame 1.
   Whether libcamera/`rpi::pisp` honours start controls from frame 1 is
   exactly what the on-Pi test measures. Design 1 does not depend on it: it
   reads the metadata of each frame.

Expected at a night frame of about 3.5 s: capture 25 s → about 4 s (frames 1–4 at preview
pacing, about 0.6 s, plus frame 5) without design 2; about 3.5 s if start controls
apply from frame 1. Preview tail: about 7 s → about 0.

## Acceptance criteria

B1. A manual still is captured from a frame whose metadata exposure and gain match the
    request within 5% and whose colour gains are within 1% of the previous
    frame's; never from a frame at the preview's exposure (frames 1–4 above).
B2. If nothing matches, it falls back to today's frame 11, with a warning.
    Auto-exposure stills are unchanged (11 frames).
B3. The recorded frame is unchanged in content: the sidecar `exposure` (actual
    exposure/gain) matches the request as before, and the meter luminance and clipped
    fraction of an early-captured frame match a same-scene frame-11 capture within
    noise (on the Pi).
B4. Start controls: a pipeline starts with the same controls as its requests.
    Measured on the Pi: which frame first carries the new exposure, for preview
    and still.
B5. On the Pi at night: `warmup_and_capture` ≪ 22–25 s, preview frames resume
    at the preview exposure immediately after a capture, and a 60 s stream
    recording shows the preview live for most of each minute.
B6. The timelapse is unaffected: captures stay once per minute and the ramp and guard
    keep working (sidecar exposure, guard log).
B7. fmt, test, clippy (Mac and Linux/aarch64), Node and Biome pass.

## Test plan (written before implementation)

- Rust unit tests (platform-neutral pure logic, so they run on the Mac): a
  `WarmupPlan`/`frame_is_capturable` decision function.
  - Manual request 3,440,629 µs × 1.0 against the measured frames 1–11 above
    captures frame 5.
  - The frame-4 transitional case is rejected (exposure still the preview's).
  - Colour gains jumping > 1% delays capture by one frame.
  - Quantisation within 5% is accepted; 6% off is rejected.
  - With no match, it falls back at frame 11.
  - Auto shutter or gain uses the fixed 11-frame target.
- Linux/aarch64 compile and clippy of `native_camera.rs` (cfg linux) in the
  vmpi build VM, or by the Pi deploy script's gates.
- On the Pi at night (needs deploy approval): the journal `warmup_frame` trace for
  B1/B4, a 60 s preview recording for B5, sidecars and the guard log for B3/B6.

## Implementation (2026-09-24)

- `src/camera.rs`: `WarmupFrame`, `capture_this_frame` (5% exposure and gain
  tolerance, 1% colour-gain settle, fallback at `STILL_CAPTURE_FRAMES`), and
  4 tests with the measured 23:54 warm-up as the fixture.
- `src/native_camera.rs` (Linux-only): the capture loop builds a `WarmupFrame` from
  each completed request's metadata, keeps a frame when `capture_this_frame`
  says so or at `target`, **breaks** after keeping it (without the break a later frame
  could replace an early keep; found in review before any run), and warns
  when a manual still falls back. `apply_controls` is split into
  `set_controls(&mut ControlList, …)`, and `start_pipeline` passes those
  controls to `camera.start(Some(&start_controls))`.
- Docs: `docs/optic-daemon-capture-performance.md` §8 and
  `docs/optic-daemon-exposure-ramping.md` §9.

A test fixture mistake on the first run: the "AWB settling" case put frame 7's gains
back at the original value (a 4.4% jump back), so the function correctly kept frame
8. The fixture now settles at the new value, and frame 7 is kept.

## Validation so far

| Check | Result |
|---|---|
| `cargo fmt --check` | pass |
| `cargo test --locked` (Mac) | pass: 268 |
| `cargo clippy --locked --all-targets -- -D warnings` (Mac) | pass; **the Linux-only `native_camera.rs` is not compiled on the Mac** |
| Linux/aarch64 compile | The vmpi build VM was not usable: it doesn't mount this worktree and has no Raspberry Pi libcamera arm64 headers. Compiled instead by the deploy script's on-Pi gates (below): **pass** |
| Hardware | see "On the Pi" |

## On the Pi (user-approved "deploy now + measure")

**Deploy** (2026-09-24 00:26:50–00:30:01 PDT): `scripts/build-deploy-optic-daemon.sh`,
exit 0. On-Pi gates: Biome, fmt, `cargo test --locked --all-targets` (263 in
the main binary), strict Clippy (this is the first Linux compile of the
`native_camera.rs` change), release build, `SUCCESS`.

**Captures after the deploy** (journal `warmup_frame` trace, night):

| Capture | Exposure (frame 1 metadata) | Kept | `warmup_and_capture` |
|---|---|---|---|
| Before (2026-09-23 23:54) | frames 1–4 at the preview's, 5–11 at 3,474,267 µs | 11 | 25,072 ms |
| #1 | 4,216,199 µs × 1.0 from **frame 1** | 2 | 12,775 ms |
| #2 | 4,226,589 µs × 1.25 from **frame 1** | 2 | 12,817 ms |
| #3 | 3,049,580 µs × 1.0 from **frame 1** | 2 | 6,230 ms |

- B4: start controls apply from frame 1 for still pipelines (no more
  preview-paced frames 1–4).
- B1: the first frame at the requested exposure (±5%) with settled white balance is kept;
  here frame 2, since frame 1 has no previous frame to compare white balance with.
  Colour gains moved ≤ 0.03% between frames 1 and 2.
- Frame 1 took about 2× its exposure in captures #1 and #2 (since_previous 8,535 and
  8,557 ms at 4.2 s) but not in #3 (3,153 ms at 3.05 s): the sensor's first
  frame after start. Possible further gain: allow frame 1 when white balance
  can be compared against the preview's last gains. Not done.
- The guard kept working across the change (after the restart reset: pull
  1.0 EV at 4.6% clipped, then 1.0 EV at 2.3%).

**Preview** (2026-09-24 20:10 PDT, dusk, user's visible dashboard with the preview on,
70 s recording as a read-only viewer, plus the journal):

- 486 frames in 70 s (≈ 7 fps at 8 fps nominal), with one gap for the scheduled
  capture: preview stopped at 20:10:00.389, capture done at 02.801 (frame 2
  kept, 2,331 ms), preview restarted at 04.423, so a **4.0 s** gap.
- B5: the restarted stream's first frames (sequence 0…) ran at the preview's
  exposure (118,745 µs × 4.90), not the still's. The slow tail seen before
  (2 frames at 3,474,267 µs) is gone.
- About 1.6 s of the gap is after the capture (JPEG encode/publish and pipeline start),
  not exposure.

**Not done:**
- B3: an A/B comparison of an early-kept frame against a same-scene frame-11 capture
  (content equivalence). The kept frames' metadata matches the request, and white
  balance is settled by construction, but no side-by-side image comparison was
  made.
- B6: an overnight check of timelapse continuity with this build (only a
  few captures observed).
- At a 1-minute interval with a night frame of about 4 s, the blackout is still about 13 s per
  capture (2 × E plus the first-frame overhead). That is inherent to stopping the
  preview for the still; a combined preview-and-still configuration would be
  needed to remove it.

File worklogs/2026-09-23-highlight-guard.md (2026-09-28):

# Dated Worklog: 2026-09-23 - Highlight Guard (Clipping Budget) for the Exposure Ramp

Status: **implemented, host-tested (Mac), and deployed to the Pi on
2026-09-23 20:27 PDT (branch build, still 0.1.31); overnight validation
pending; not user-accepted.** The test plan was written before any
`src/` edit. On-Pi validation needs the user's approval and a deploy of `main`
plus this branch (see "Proposed overnight comparison"). Committed and opened
as PR #18 (https://github.com/keefo/optic/pull/18) with the user's approval on
2026-09-23; not merged.

## Objective

In overnight footage, street lamps and building lights bloom into large
blown-out white areas. The exposure ramp (`src/exposure_ramp.rs`, PR #16)
meters a trimmed log mean and opens up until it reaches the night target. It
already measures `FrameMeter.clipped_fraction` but never uses it. Give
clipping a **budget**: a small fraction of samples may clip (emissive lamps
should), and above that the ramp backs off. Design:
`docs/optic-daemon-exposure-ramping.md` §5.6.

## Premise check against real data (2026-09-23)

Source: `/Users/admin/Pictures/Optic` (read-only; nothing moved, renamed or
deleted). 1,339 scheduled captures, `master_archive`, one per minute,
2026-09-22 15:12 → 2026-09-23 13:30 PDT. Each has a `.log.json` sidecar.

**Correction to the task brief.** The brief said exposure ramping was not yet
deployed on the Pi (0.1.31), so last night's frames were not ramped. That is
wrong:

- `GET /api/status` on the Pi (read-only, port 8000) reports `version:
  0.1.31`, `config.schedule.exposure.mode: AutoRamp` with default settings
  (`night_drop_ev 2`, `max_step_ev 1/3`, `smoothing 0.5`, `max_gain 8`), and a
  live ramp snapshot (`seed: false`, `max_shutter_us: 4227272`).
- `optic-daemon.service` has been active since 2026-09-22 14:14 PDT (before the run).
- The sidecars' shutter varies smoothly frame to frame. At night it caps at exactly
  4,227,272 µs, which is `max_shutter_for_gap` for a 60 s interval,
  `(0.8·60 s − 1.5 s)/11`. Above that cap the gain rises (1.03–1.30).
- `worklogs/2026-09-21-exposure-ramping.md` already records Part 1 as deployed
  on 2026-09-22. The design doc's status line still said "Not deployed". It is
  corrected in this change.

So these frames **are ramped** frames: they show what the current ramp does,
which is the right baseline for the guard. They carry no actual-exposure
metadata (0.1.31 predates `worklogs/2026-09-22-capture-exposure-metadata.md`),
so "exposure" below means the *planned* shutter × gain from the sidecar.

**Method.** A scratch Python script (scratchpad venv: Pillow, NumPy, SciPy;
not committed) replicates `meter_yuv420` on the JPEG luma. That means a 1/16
sample grid, 2% trims, γ 2.2 log mean, and clipped = Y ≥ 250. It ran on all
frames at 1/4 resolution. Connected-component blob sizes were measured at
full resolution (4056×3040) on selected frames. The meter reproduces the
daemon's target: night L = 0.045 = 0.18 · 2⁻², exactly the −2 EV night target.

### Findings

| Period | Exposure | Mean L | Clipped | p95 / p99 luma | Y ≥ 200 |
|---|---|---|---|---|---|
| Day (sun > +3°) | 0.6–5 ms | 0.14–0.30 | 0–7% (sky, glass) | 190–250 / 205–255 | 2–19% |
| Sun +2° … −3° | 28–240 ms | 0.09–0.13 | 0.01–0.08% | 145–172 / 177–220 | < 1% |
| 19:42–21:15 (room lights on) | 0.63–0.95 s | 0.044–0.086 | 0.35–0.72% | 154–183 / 218–244 | 1.5–2.5% |
| Night 21:27–06:00 (n = 514) | 3.1–4.2 s | ≈ 0.045 | median 2.65%, p90 2.96%, max 3.7% | 229 / 254 | 7–11% |
| Dawn, sun −9° … −4° | 4.2 s × 1.0–1.3 | 0.06–0.09 | 3.2–4.0% | 245 / 255 | 10–12% |

**Mechanism (21:16 and 21:22).** The camera shoots through a window. Room
lights reflected in the glass were part of the metered scene. When they went
off, the scene fell 1.5 EV and then 1.9 EV (2.2 EV net). The ramp opened
0.64 s → 3.1 s (+2.3 EV) and brought the mean back to target. The clipped
fraction went from 0.35% to 2.5%, and the largest blob from ~330 to ~3,200 px at
1/4 resolution. The store entrance, parking-lot floodlights and canopy bloom.

**Natural experiment (the −1.6 EV frames).** Dozens of night frames
(21:47–05:25, often every 3–5 minutes) came out about 1.6 EV darker than their
neighbours at the same planned shutter. The cause is not determined; it is
recorded as a follow-up. They show the same scene at about −1.6 EV and look
visibly better:

| Full-resolution frame | Clipped (Y ≥ 250) | Largest blob | Blobs ≥ 1000 px | Y ≥ 230 |
|---|---|---|---|---|
| 21:12, 0.64 s (room lights on) | 0.41% | 5,504 px (0.045%) | 8 | 0.85% |
| 01:26, 3.5 s (ramp at target) | 2.82% | 56,374 px (0.457%) | 46 | 5.47% |
| 01:27, same shutter, −1.6 EV | 1.19% | 35,214 px (0.286%) | 13 | 2.00% |

**Clip response.** Clipped area roughly doubles per EV. Measured slopes: the
21:22–21:26 sweep gives +1.3 EV → ×2.9 (1.18 doublings/EV). The −1.6 EV frames
give ×2.4 (0.78 doublings/EV).

**Transients.** Excluding the dark frames, the largest single-frame rise over
the neighbouring frames' median was +0.84 percentage points (×1.3). The
median frame-to-frame deviation was 0.07 points. Headlights are small next to
the lamps in this scene.

**Percentiles.** At night p99 = 254 (the lamps) and p95 = 229 (lit lot
surfaces). This confirms the rejection of a p99 target. A clipped-fraction
budget alone bounds the p95 region, so no percentile target is added.

## Decisions (user, 2026-09-23, via the question tool)

| Question | Decision |
|---|---|
| Default budget | **1%** of metered samples (≈ −1.5 EV at night on this scene). |
| When active | **Sun below 0°**; no station → inactive. |
| Back-off | **≤ 1 EV per frame after two consecutive over-budget frames**. Recovery 1/12 EV per frame, only below budget/2. |
| UI | **Under Advanced** on the dashboard (percent, 0 = off). |

Also chosen as defaults, without separate questions: a −3 EV floor for the
guard, and the guard learns only from captured frames, not preview frames
(design §5.6).

## Acceptance criteria

G1. **Darker with lamps, and stable.** A night scene replayed from the measured
    2026-09-22 sequence, with the default 1% budget, converges to an exposure at
    least 1 EV darker than the same replay with the guard off. After
    convergence the simulated clipped fraction stays ≤ 1.5 × budget, and the
    planned exposure moves < 0.2 EV frame to frame (no hunting).
G2. **Transients ignored.** A single frame with 3× the clipped fraction moves
    the planned exposure by 0 EV. A sustained rise is pulled within 3 frames.
G3. **Never brightens.** For any state, observation and sun elevation,
    `H ≤ 0`, and the guarded plan is ≤ the plan with the guard off.
G4. **Daylight unchanged.** With the sun ≥ 0°, no station, or a budget of 0,
    plans are identical to the pre-guard behaviour, even with 5% clipping.
G5. **Pull speed and floor.** A pull is at most 1 EV per frame and is not
    slowed by `max_step_ev`. `H` never goes below −3 EV. Recovery is at most
    1/12 EV per frame, and only below budget/2.
G6. **Robust to exposure faults.** A frame the camera exposed 1.6 EV darker
    than planned does not trigger recovery or a pull by itself.
G7. **Config.** `clip_budget_percent` defaults to 1.0. Older configs without
    the field deserialize to it. `validate` rejects values outside 0..=10 with
    422 through the existing endpoints, and `sanitized` clamps them.
G8. **Preview.** `observe_preview` leaves the guard state unchanged. The live
    plan includes `H` and reports it (`LiveExposurePlan.highlight_ev`). The
    dashboard caption shows it when it is non-zero.
G9. **UI.** An Advanced field "Highlight clip budget (%)" round-trips the
    setting.
G10. `cargo fmt --check`, `cargo test --locked`, `cargo clippy --locked
    --all-targets -- -D warnings`, and `node --test tests/web/*.test.js` pass.

## Test plan (written before implementation)

Rust unit tests in `src/exposure_ramp.rs`:

1. `guard_pulls_after_two_over_budget_frames` (G2, G5): the first frame over
   budget leaves `H = 0`; the second pulls by min(excess, 1 EV).
2. `guard_ignores_a_single_bright_frame` (G2): steady at budget, one ×3
   frame, then steady → planned exposure unchanged.
3. `guard_pull_is_not_slowed_by_the_step_limit` (G5): after a 1 EV pull the
   next plan drops about 1 EV even with `max_step_ev = 1/3`.
4. `guard_floor_and_slow_recovery` (G5): sustained heavy clipping stops at
   −3 EV; clipping below budget/2 recovers 1/12 EV per frame; the hold band
   between budget/2 and budget leaves `H` alone.
5. `guard_never_brightens` (G3): a grid of states, clip fractions, sun
   elevations and budgets → `H ≤ 0` and the guarded plan ≤ the unguarded plan.
6. `guard_is_inactive_in_daylight_without_station_or_with_zero_budget` (G4):
   bit-identical plans versus a guard-free state, with 5% clipping.
7. `guard_ignores_an_exposure_fault_frame` (G6).
8. `preview_frames_leave_the_guard_alone` (G8).
9. `replay_2026_09_22_night_with_and_without_guard` (G1): a closed-loop replay of
   the measured 21:10–22:40 sequence (per frame: measured scene EV and
   clipped fraction at the planned exposure). The simulated clipped fraction
   at another exposure scales as 2^(ΔE), the measured ≈ 1 doubling per EV.
   Guard off reproduces the runaway (≥ 2% clipped). Guard on converges ≥ 1 EV
   darker, clipped ≤ 1.5%, and stable.
10. Settings tests extended: default, round-trip of an old config without the
    field, `validate` bounds, `sanitized` clamp (G7).

Scheduler (`src/optic_scheduler.rs`): the existing `live_exposure_plan` test
is extended to check `highlight_ev` (G8).

Node (`tests/web/scheduled-exposure.test.js`): the caption mentions the
guard only when `highlight_ev` ≤ −0.05 (G8/G9).

Target environment: Mac for all of the above. On the Pi (needs user approval
and a deploy of `main` + this branch; the version is bumped at merge), one
guarded night compared against the 2026-09-22 frames measured here.

## Scope note

This track owns `src/exposure_ramp.rs` and
`docs/optic-daemon-exposure-ramping.md`, plus the minimum in
`src/optic_scheduler.rs` / `src/web/scheduled-exposure.js` to surface the
setting. Surfacing the field also needs one `<label>` in `src/web/index.html`
(outside the listed files, recorded here). No `Cargo.toml` version bump.

## Implementation (2026-09-23)

- `src/exposure_ramp.rs`
  - `RampSettings.clip_budget_percent` (default 1.0, `validate` 0..=10,
    `sanitized` clamps; NaN falls back to 1.0; older configs get the default
    through the existing `#[serde(default)]`).
  - `HighlightGuard { offset_ev, last_pull_ev, previous_excess_ev }` in
    `RampState.highlight`, and `HighlightGuard::next`, which implements the
    pull, hold, recover, floor and gate rules. Also `guard_active(sun)`
    (sun < 0°, never without a station).
  - `plan`: `E_desired = min(target − Ŝ, E_max) + H`. The downward step limit
    is widened by `last_pull_ev`.
  - `observe` takes the shot's `sun_elevation_deg`. The excess is
    `log2(clipped/budget) + (E_planned − E_actual)`. Seeds reset the guard.
  - `observe_preview` leaves the guard unchanged.
- `src/optic_scheduler.rs`: passes the shot's sun elevation to `observe`,
  logs each pull (`highlight guard darkened the ramp`), and adds
  `LiveExposurePlan.highlight_ev`. Two test literals and the
  `live_exposure_plan` test are updated.
- `src/web/scheduled-exposure.js`: `RAMP_DEFAULTS.clip_budget_percent`, the
  Advanced field binding, and `describeHighlightGuard`, used in the caption.
- `src/web/index.html`: the *Highlight clip budget (%)* input under Advanced
  (outside the listed files; see "Scope note").
- `tests/web/scheduled-exposure.test.js`: caption and defaults tests.
- `docs/optic-daemon-exposure-ramping.md`: §3 decision row, §4 field, §5.3
  plan formula, new §5.6, §7 status/log, §9 follow-ups, and the §10 Advanced list.
  The status line was corrected (the ramp *is* deployed as 0.1.31), and a
  stale "white-balance rate" Advanced field was removed from the §10 list.

A defect found during implementation review, before any run: the first
version added `H` *before* the shutter × gain ceiling clamp. In a scene too
dark for the ceiling, the offset would have disappeared into the headroom
above it, so the guard could reach its floor without changing the frame. It
is fixed by applying `H` below the ceiling. Regression test:
`guard_darkens_from_the_exposure_ceiling_in_a_very_dark_scene`; the old
ordering plans `ceiling − 0.67` instead of `ceiling − 1`.

Two test-setup mistakes were fixed during the first run: the plan rounds the
shutter to whole µs (so it is compared with `planned[0]`, and within 1e-5 of
the reference), and the fault test's guarded state now has a matching
guarded anchor. Neither was a guard defect.

## Validation (Mac, 2026-09-23)

| Check | Result |
|---|---|
| `cargo fmt --check` | pass |
| `cargo test --locked` | pass: 256 passed (was 246 before this change; 31 in `exposure_ramp`) |
| `cargo clippy --locked --all-targets -- -D warnings` | pass |
| `node --test tests/web/*.test.js` | pass: 26 tests |
| `npx @biomejs/biome@2.5.14 ci` (CI's pinned version) | pass: 13 files, no fixes |
| Linux/aarch64 compile (vmpi or Pi) | **not run**. No Linux-only code was touched, and the new items are all used on every platform. |
| On-Pi / overnight | **not run** (needs approval and a deploy) |

New tests and what they showed:

| Test | Criterion | Observed |
|---|---|---|
| `guard_pulls_after_two_over_budget_frames` | G2, G5 | Frame 1 at 2.65%: `H = 0`. Frame 2: `H = −1` (capped from 1.41 EV) |
| `guard_pull_is_not_slowed_by_the_step_limit` | G5 | The plan drops 1.0 EV in one frame with `max_step_ev = 1/3` |
| `guard_darkens_from_the_exposure_ceiling_in_a_very_dark_scene` | G5 | The plan is at ceiling − 1 EV with 5 EV of unguarded headroom |
| `guard_ignores_a_single_bright_frame_but_catches_a_sustained_rise` | G2 | One ×3 frame: 12 identical plans. Sustained ×3: third frame > 0.5 EV darker |
| `guard_stops_at_its_floor_holds_in_band_and_recovers_slowly` | G5 | Stops at −3 EV. Holds at 0.7%. +1/12 EV per frame at 0.1%, capped at 0 |
| `guard_never_brightens` | G3 | 2,880 combinations of state, clipping, sun, budget and fault: `H ∈ [−3, 0]`, guarded plan ≤ unguarded plan |
| `guard_is_inactive_in_daylight_without_a_station_or_with_zero_budget` | G4 | Sun +10°, 0°, none, budget 0: plans bit-identical to a no-clip reference at 5% clipped. At dawn a leftover −1.5 EV eases +1/12 EV |
| `guard_judges_clipping_at_the_planned_exposure` | G6 | Frames −1.6/+1/0/−1.6 EV off plan leave `H` at −1 |
| `preview_frames_leave_the_guard_alone` | G8 | Guard state unchanged at 0% and 50% clipped |
| `replay_2026_09_22_night_with_and_without_the_guard` | G1 | See below |
| Settings tests (extended) | G7 | Bounds, NaN, clamp, old-config default |
| `live_exposure_plan` test (extended) | G8 | `highlight_ev` −1.25 reported; 0 while seeding |

**Replay of 2026-09-22 21:10–22:40 (91 measured frames, closed loop; clipped
fraction scaled at 1 doubling per EV).** The numbers came from a temporary
`eprintln!`, which was removed afterwards; the committed test asserts the
bounds:

| | Settled exposure, mean of last 30 frames (log2 µs) | Clipped, settled (every 5th frame printed) |
|---|---|---|
| Measured on the Pi | 21.702 (≈ 3.4 s) | 2.4–2.7% |
| Replay, guard off | 21.703 | 2.54–2.70% |
| Replay, guard on (1%) | 20.267 (≈ 1.3 s), **1.44 EV darker** | 0.92–1.02% |

The test asserts the bounds over all 30 settled frames: clipped ≤ 1.5%, and a
frame-to-frame change < 0.2 EV.

With the guard off, the replay reproduces the Pi's exposure to within
0.001 EV, which supports the replay model. With the guard on, the first pull
lands on the second over-budget frame after the 21:22 switch-off (frame 16,
−1.1 EV). The guard settles within 2 frames and does not hunt. It is never
brighter than the unguarded run at any frame.

## Limitations and risks

- **The model is from one night and one scene.** The 1 doubling-per-EV clip
  response and the constants (1 EV pull, 1/12 EV recovery, −3 EV floor, 0°
  gate, hold band budget/2 to budget) are fitted to 2026-09-22. They need
  checking after a guarded night.
- **The replay is a model, not the camera.** It scales clipping analytically.
  Real bloom also depends on the ISP tone curve and the lens (haze through the
  window glass).
- **The guard learns from captured frames only.** A ramp started from preview
  frames shows the unguarded exposure until two night captures have run.
- **Frames 1.6 EV darker than planned (not caused by this change).** Dozens
  of frames on 2026-09-22 (21:47–05:25) came out about 1.6 EV darker than
  planned at the same requested shutter. The guard now discounts them. The
  cause is unknown: 0.1.31 sidecars have no actual-exposure metadata. The
  capture-exposure-metadata work will show whether the camera used a shorter
  exposure. This is a separate issue and should get its own worklog.
- **Dawn.** At sun −4° the ramp was already at the 4.2 s cap with 4% clipped.
  The guard will darken dawn twilight too; that is intended, but it is
  unobserved.
- The dashboard's Advanced field has not been exercised in a browser
  (it is covered by the pure-function tests and the generic field binding only).

## Proposed overnight comparison (needs user approval)

1. Merge this branch into `main` via a PR. The version is bumped at merge
   (not here). Then deploy the merged build to the Pi. The Pi is shared and
   the daemon is a system service, so the user schedules the deploy and
   restart.
2. Keep the same rule (`every1min`, `master_archive`), the same camera
   position and AutoRamp defaults, so the budget is 1%.
3. The next morning, rerun the scratch measurement on the new frames and
   compare with the 2026-09-22 tables above. Expected at night: clipped ≈ 1%
   (was 2.65%), exposure ≈ 1.2–1.5 s (was 3.1–4.2 s), largest blob ≲ 0.3% of
   the frame (was 0.46%), mean L ≈ 0.016 (about −1.5 EV). Daytime frames
   should match 2026-09-22 frame for frame in exposure behaviour.
4. Check `journalctl -u optic-daemon | grep "highlight guard"` for the pull
   times, and the new sidecar `exposure.meter.clipped_fraction` values.
5. Watch for hunting (the frame-to-frame exposure should stay < 0.2 EV at night)
   and for a dawn that looks too dark.

## User verification

1. Dashboard → Scheduled exposure → Advanced: *Highlight clip budget (%)*
   shows 1. Change it, then Save Settings, and confirm it persists.
2. After an approved deploy, while the guard is active, the caption shows
   "highlight guard −x EV" at night.
3. Review the overnight footage for lamp bloom.

## Deploy (2026-09-23, user-requested: "now please build and deploy")

- What was deployed: branch `highlight-guard` at `9e81009` (= `main` 3b8cd1a +
  the guard). PR #18 is **not merged**, and the version is **not bumped**, so
  the Pi still reports `0.1.31`. The guard build is identified by the
  `exposure_plan.highlight_ev` field in `/api/status`.
- Command: `scripts/build-deploy-optic-daemon.sh` (full path) from the Mac
  worktree. Exit 0. The script's on-Pi gates all passed: Biome, `cargo fmt
  --check`, `cargo test --locked --all-targets` (4 + 251 passed),
  strict Clippy, and the release build (1 m 34 s). It installed with rollback
  protection and printed `SUCCESS: optic-daemon 0.1.31 is active`.
- The service was stopped for the build from about 20:24 to 20:27:42 PDT, so
  the every-minute timelapse has a gap of about 3–4 frames there. `NRestarts=0`.
- Observed after the restart, read-only:
  - `/api/status`: `exposure_plan.highlight_ev: 0.0` and
    `config.schedule.exposure.clip_budget_percent: 1.0`. The ramp is not
    seeding; it was already seeded by preview frames.
  - Scheduled captures at 20:28:07 and 20:29:06 succeeded and were ramped
    (0.88 s and 0.79 s, gain 1.0, sun −13.9°).
  - The synced sidecar `…1790220546688.log.json` records the actual exposure
    (786,285 µs against 786,907 µs requested) and the daemon's own meter:
    `clipped_fraction` 0.645%. That is inside the hold band (0.5–1%), so
    `H = 0` is the expected state; last night at this hour it was 0.4–0.7%.
- Still to do: the overnight comparison (see above). Pulls, if any, appear in
  `journalctl -u optic-daemon | grep "highlight guard"`.

## Part 2: making the budget visible in the live preview (2026-09-23)

Status: **implemented, host-tested (Mac), deployed to the Pi on
2026-09-23 20:46 PDT (uncommitted working tree, still 0.1.31), and verified
live at night in a browser tab (see "Part 2 on the Pi"); not user-accepted.** The
test plan was written before any `src/` edit for Part 2.

**Why.** After the deploy, the user asked whether the Highlight clip budget
shows in the preview. It did not, or not usefully: the guard moved only on
scheduled captures, once a minute, and never while the scheduler was paused. User: "if a feature can not
preview the see the impact, it is useless." Of the ideas brainstormed, the user chose all four
(question tool): (1) the preview uses the guard's target, (2) a clipping
overlay, (3) a live readout, (4) hold-to-compare. Design:
`docs/optic-daemon-exposure-ramping.md` §5.7.

**Facts checked before designing.** The preview is MJPEG decoded into an `<img>`.
Focus tools already paint an overlay canvas from each decoded frame
(`focus-tools.js`). Every preview frame is already metered on the Pi
(`PreviewFrame.meter`), but only exposure, gain and colour gains reach the
browser (`X-Optic-*` headers, `web.rs::mjpeg_part`). The dashboard polls
`/api/status` every 3 s, and staging an exposure change triggers an immediate
refresh (`app.js` `scheduled-exposure-change`). The preview override is
recomputed when the plan key changes.

**Scope note.** Beyond the files listed for this track, Part 2 also touches
`src/web.rs` (one header), `src/web/app.js` (reading it, plus the compare
button wiring), `src/web/focus-tools.js` (the Clipping tool), and
`src/web/index.html` (buttons and the guard line). Capture behaviour (§5.6
`H`) is unchanged.

### Acceptance criteria

P1. **The budget moves the preview without a capture.** With a fixed ramp
    state (no new frames), changing `clip_budget_percent` changes
    `highlight_target_ev` and `LiveExposurePlan.preview` on the next status
    call.
P2. **Target formula and gates.** `H* = clamp(log2(budget) − ĉ − min(u, E_max),
    −3, 0)`. It is 0 with the sun ≥ 0°, without a station, with budget 0, or
    without a clip estimate. It is never above 0, and `preview` is never brighter than
    `preview_unguarded`.
P3. **What learns.** `ĉ` learns from captures and preview frames, normalised
    by the actual exposure (a frame exposed 1 EV differently with the
    correspondingly scaled clipping gives the same `ĉ`). Preview frames
    still leave `H`, `last_pull_ev`, `previous_excess_ev` and
    `planned_log2_exposure` alone.
P4. **Preview closed loop converges.** With a simulated preview loop, where each
    iteration measures clipping at the preview exposure with a true slope of
    0.8, 1.0 or 1.2 doublings per EV, clipping converges to within ±20% of the budget
    within 8 iterations and stays there. With lamp cores that always clip
    (a floor above the budget), it stops at −3 EV and never goes below it.
P5. **Captures unchanged.** All Part 1 guard tests and the 2026-09-22 replay
    pass unchanged.
P6. **API.** `LiveExposurePlan` gains `preview`, `preview_unguarded`,
    `highlight_target_ev` and `highlight_active`. The JS override uses
    `preview`, falls back to the plan for an older daemon, and uses
    `preview_unguarded` while compare is held. A change of either value or of the
    compare state re-requests the stream.
P7. **Readout.** `X-Optic-Clipped` is on every MJPEG part. The guard line
    formats active, inactive (sun) and off states, and the live clipped
    percentage.
P8. **Overlay.** The *Clipping* tool marks exactly the pixels whose BT.601
    luma ≥ 250 (pure function, tested), and toggles like the other tools.
P9. `cargo fmt --check`, `cargo test --locked`, `cargo clippy --locked
    --all-targets -- -D warnings`, `node --test tests/web/*.test.js`, and
    Biome 2.5.14 `ci` pass.
P10. **On the Pi** (after an approved deploy): changing the budget visibly changes
    the preview brightness at night within a few seconds; hold-to-compare
    shows the bloom; the overlay and readout agree with the frame.

### Test plan (written before implementation)

Rust (`src/exposure_ramp.rs`):

1. `clip_estimate_is_normalised_by_actual_exposure` (P3).
2. `preview_frames_learn_the_clip_estimate_but_not_the_capture_guard` (P3;
   extends the Part 1 preview test).
3. `highlight_target_follows_the_budget_without_new_frames` (P1, P2).
4. `highlight_target_is_zero_when_the_guard_cannot_act` (P2): sun ≥ 0,
   no station, budget 0, no estimate.
5. `preview_plans_bracket_the_capture_plan` (P2, P6): `preview` ≤
   `preview_unguarded`; equal to the plan when `H* = H = 0`.
6. `simulated_preview_loop_converges_to_the_budget` (P4): slopes 0.8, 1.0 and 1.2,
   plus a clipping floor case.
7. The existing Part 1 tests and the replay, unchanged (P5).

Rust (`src/optic_scheduler.rs`): extend the `live_exposure_plan` test for
the new fields (P6). `src/web.rs`: extend the MJPEG part test for
`X-Optic-Clipped` (P7).

Node (`tests/web/`): `describeGuardLine` states (P7); preview override
source selection including compare and fallback (P6); `clippedMask` on
synthetic RGBA with BT.601 threshold edges (P8).

Target environment: the Mac for all of the above, then the Pi at night for P10
(deploy needs user approval).

### Part 2 implementation

- `src/exposure_ramp.rs`: `HighlightGuard.clip_scene_ev` (the smoothed,
  budget-independent clip estimate), learned from every frame by `observe`
  and `observe_preview`. It survives a budget-0 guard reset and is floored at
  1e-4. `highlight_target_ev` (`H*`). `ExposureSetting`, `PreviewPlans`,
  `preview_plans` (`preview = clamp(E_plan − H + H*)`, `unguarded =
  clamp(E_plan − H)`). `plan` is refactored onto `ExposureLimits` and
  `unguarded_log2_exposure` with the same arithmetic; all Part 1 tests and
  the replay pass unchanged. The capture guard's `H` logic is untouched.
- `src/optic_scheduler.rs`: `LiveExposurePlan.highlight_target_ev`,
  `highlight_active`, `preview` and `preview_unguarded`.
- `src/web.rs`: the `X-Optic-Clipped` MJPEG part header.
- `src/web/app.js`: `frameMetadata().clippedFraction`.
- `src/web/scheduled-exposure.js`: `previewSource` (target, compare, or a
  fallback for an older daemon) feeds the preview override. The plan key also
  covers the preview plans. `describeGuardLine` renders the guard line,
  refreshed at most every 500 ms from preview frames. Hold-to-compare works
  with the pointer (captured) and with Space/Enter. The Part 1
  `describeHighlightGuard` caption fragment is replaced by the guard line.
- `src/web/focus-tools.js`: the `clippedMask` pure function and the
  *Clipping* toggle, drawing zebra stripes on the shared overlay canvas.
- `src/web/index.html` and `styles.css`: the Clipping button, the guard
  line and the compare button.
- Docs: `docs/optic-daemon-exposure-ramping.md` §5.6 (a pointer to the new
  section), the new §5.7, and a §10 bullet. `docs/optic-daemon-focus-tools.md`
  gets the controls list, the function table and a new §3.3.1.

A mistake caught in review, before any run: the first draft of the
`live_exposure_plan` test extension had a tautological assertion. It was
replaced with the real property (no clip estimate → `preview ==
preview_unguarded`).

### Part 2 validation (Mac)

| Check | Result |
|---|---|
| `cargo fmt --check` | pass |
| `cargo test --locked` | pass: 262 (Part 1 had 256; `exposure_ramp` 36, all Part 1 tests unchanged, replay included) |
| `cargo clippy --locked --all-targets -- -D warnings` | pass |
| `node --test tests/web/*.test.js` | pass: 29 |
| `npx @biomejs/biome@2.5.14 ci` | pass: 13 files, no fixes |
| Browser check of the new controls | **not run**: there is no local camera, so it needs the Pi |
| P10 on the Pi at night | **not run**: needs deploy approval |

New or changed tests: `clip_estimate_is_normalised_by_actual_exposure`
(P3), `highlight_target_follows_the_budget_without_new_frames` (P1/P2: 1% →
−1.406 EV and 0.5% → −2.406 EV at 2.65%; 0.1% hits the floor; the preview moves
1.406 EV between budgets with no new frame),
`highlight_target_is_zero_when_the_guard_cannot_act` (P2),
`preview_plans_bracket_the_capture_plan` (P2/P6),
`simulated_preview_loop_converges_to_the_budget` (P4: slopes 0.8/1.0/1.2 ×
shortfall 0/0.8 EV all within ±20% of the budget from iteration 8 to 20;
2% lamp-core floor → stops at −3 EV), `preview_frames_leave_the_guard_alone`
(now also checks that the estimate learns), `live_exposure_plan` (P6),
`mjpeg_part_carries_the_clipped_fraction` and the header in the existing
part test (P7). Node: `previewSource`, `describeGuardLine` (P6/P7), and
`clippedMask` threshold edges at Y = 248.7 and 250.4 (P8).

### Part 2 limitations

- The preview target and the timelapse `H` converge to the same goal by
  different routes (a solver versus rate-limited steps with a hold band), so they can differ by
  up to about the hold band (≈ 1 EV) until clipping settles. The guard line shows both.
- The preview meters at lower resolution than a still, which is not yet
  measured on the Pi (P10). If the preview reads systematically lower, the
  target will be too bright relative to the timelapse.
- The overlay runs on the ≤ 960 px working copy. The daemon's number is
  authoritative.
- As before, every status poll that changes the preview plan re-requests
  the stream, and the target adds one more source of such changes.

### Part 2 on the Pi (2026-09-23, user-approved "deploy now + verify live")

**Deploy.** Ran `scripts/build-deploy-optic-daemon.sh` from the worktree
(uncommitted Part 2 changes). Exit 0. On-Pi gates: Biome, fmt, `cargo test`
(257 passed in the main binary), strict Clippy, release build. It printed
`SUCCESS`. The daemon was down from 20:43:46 to 20:46:40 PDT, so the
timelapse lost about 3 frames. Afterwards `/api/status` exposed `highlight_active`,
`highlight_target_ev`, `preview` and `preview_unguarded`. Scheduled captures
continued (for example 20:51:07, success).

**Live check** (Chrome automation tab on `http://optic.local:8000/`, sun
about −17°, Master Archive preview downsampled to 8 fps):

| P | Observed |
|---|---|
| P7 header | A raw MJPEG part carried `X-Optic-Clipped: 0.004496…` (0.45%) |
| P7 readout | Guard line: "Highlight guard · budget 1.00% · clipped now 0.53% · preview 0.0 EV · timelapse 0.0 EV". A target of 0 is correct: tonight is under the 1% budget |
| P1 budget → preview | Setting 0.25% in the Advanced field moved `highlight_target_ev` to −0.96 EV and `preview` to 0.356 s (against 0.692 s unguarded) within 1.5 s, with no captured frame in between |
| P10 convergence | The live readout then showed clipped 0.23–0.30% at a 0.25% budget, and the target settled at −0.69 to −0.81 EV as the scene changed. The room-light reflections visible in the window went on and off during the test, and the unguarded exposure moved from 0.69 s to 1.07 s |
| P6/P10 compare | Space held on *Hold to compare*: `aria-pressed=true`; the camera's frames went to 1.58× the exposure (+0.66 EV), clipped 0.27% → 0.61%. After release: `aria-pressed=false`, and the frames returned to the guarded side (0.40 s, 0.16%) |
| P8/P10 overlay | *Clipping* on: red zebra marks on the store entrance, the parking-lot floodlights and the lamp posts, the areas that bloomed on 2026-09-22 |

**Findings and caveats from the live check:**

- **The automation tab was hidden** (`visibilityState: hidden`, 0 rAF
  callbacks/s). `renderMjpegFrame` awaits two animation frames before calling
  the frame hooks, so in a hidden tab the guard line, the overlay and the
  clipped readout only updated while a screenshot was being taken. The hidden tab's timer
  throttling also delayed the 3 s status poll. That explains an observed gap
  of 0.8× between the planned preview and the frames' actual exposure: the UI's
  override (535k µs) was about 0.96× the latest plan (559k µs), and the rest
  was stream lag. This is existing dashboard behaviour, not caused by this change. It is
  **not verified that a visible dashboard tracks the plan within one poll**;
  that is left to the user.
- **The pointer path of hold-to-compare was not exercised** (only the keyboard
  path). A review of it found that `setPointerCapture` ran *before*
  `setComparing(true)`, so a refused capture would have stopped compare
  from engaging. **Fixed after the deploy** (compare first, capture as best effort).
  Node 29/29 and Biome pass. **This fix is not deployed.**
- The budget was restored to exactly 1% afterwards. The staged exposure settings are
  identical to before (`config_staged` was already true from edits that
  aren't ours). Closing the automation tab stopped the camera preview through
  `pagehide` → `/api/stream/stop`. Scheduled captures are unaffected.
- A probe of a nonexistent `/api/config` route logged one harmless `ERROR
  failed to load web asset … api/config` at 20:51:15.
- The preview-to-still clipped-fraction ratio (a Part 2 limitation) is still
  unmeasured.

## Part 3: Scheduled exposure preview hunts, and its colour shifts (2026-09-23)

Status: **implemented, host-tested (Mac), deployed to the Pi on 2026-09-23
23:52 PDT (uncommitted working tree, still 0.1.31), and verified on the camera
for Q7 (see below); not user-accepted.** The test plan was written before any
`src/` edit for Part 3.

**Report (user, about 21:55).** With *Scheduled exposure* on, the live preview's
colour keeps shifting "like WB is changing": warmer when the Shutter field
drops to about 600 ms, cooler at 700–800 ms. Unchecking Scheduled exposure
stops it. The user identified it as a Scheduled exposure bug, not a
clip-budget one, and chose to fix it on this branch.

**Evidence** (a 40 s recording of the live MJPEG stream as a second
read-only viewer; 319 frames; Master Archive preview downsampled to 8 fps,
AWB preset Daylight, Denoise Auto, sun −27°):

- **Not white balance.** `X-Optic-Colour-Gains` was identical in all 319
  frames (3.2061546, 1.4414065).
- **The exposure never settles.** Shutter was fixed at 118,745 µs (frame-time
  limited), and analogue gain took **40 distinct values between 5.22 and
  6.87** (0.40 EV peak to peak, sd 0.12 EV). **86 control revisions in 40 s**:
  the dashboard re-requested the stream about every 0.47 s.
- **Colour follows gain.** Frame R/G ranged 1.08–1.41 and B/G 0.40–0.49,
  with corr(gain, B/G) = 0.81 and corr(gain, R/G) = 0.67. Higher gain looked
  cooler, which matches the report. The shift is in the shadows: R/G of the
  darker half ranged 0.98–1.76 (sd 0.18), while the brightest 5% held at
  1.04–1.14 (sd 0.02).
- **Root cause of the hunting.** The per-frame scene estimate `log2 L − log2(e·g)`
  was not exposure-invariant at these gains: corr(scene_ev, log2 e·g) =
  **0.93**, with a range of 0.48 EV over 0.40 EV of exposure (≈ 1.2 EV of
  apparent scene change per EV of gain). A higher preview gain makes the scene
  read brighter, so the plan asks for less, and the reverse. Preview frames update
  the estimate at frame rate with weight 1 − smoothing = 0.5, so the loop
  gain is above 1 and it oscillates.
- **An amplifier.** `onStatus` calls `notifyChange` whenever the plan's
  shutter/gain (Part 2: also the preview plans) changes, and `app.js`'s
  `scheduled-exposure-change` handler calls `refreshStatus()` straight away.
  The new plan differs again, so the dashboard re-requests at network round-trip rate
  instead of once per 3 s poll. This loop is in the PR #16 code (the key
  was `[seeding, shutter_us, gain]`); Part 2 only added fields to the key.
- Why the colour moves with gain: most likely the sensor/ISP rendering of
  near-black at different analogue gains (noise floor, black level, gain-
  dependent colour denoise). This has not been isolated. With a stable exposure it no
  longer flickers; it only changes when the exposure really changes.
- Stills are not affected in the same way: on 2026-09-22 the captured scene estimate
  held at about −26.2 across 3.1–4.2 s at gain 1.

### Acceptance criteria

Q1. **Time-based preview learning.** `observe_preview` blends the scene and
    clip estimates by `1 − exp(−Δt / 5 s)`, where Δt is the time since the state
    was last updated (clamped to 0 or more). A burst of frames at 8 fps moves the
    estimate by the same amount as one frame after the same total time, within 1%.
    Captures (`observe`) keep per-frame `smoothing` and are unchanged.
Q2. **The loop converges.** A simulation with the measured bias (the scene
    reads 1.2 EV brighter per EV of preview exposure), a 3 s poll and
    8 fps frames settles: after 60 s the planned preview exposure moves less than 1/6 EV
    between polls, and the peak-to-peak swing over the last 30 s is below 1/6 EV. The
    same simulation with the old per-frame learning keeps a swing of ≥ 1/3 EV
    (a regression guard that shows the test detects the bug).
Q3. **No re-request storm.** A plan-driven change re-requests the stream
    without an immediate extra status fetch. User edits (the toggle,
    settings) still refresh status immediately, so a budget change still shows
    within about 1 s.
Q4. **Hysteresis.** A new preview exposure is sent (a controls-only
    `/api/stream/reconfigure`, with no pipeline restart) only when the preview source
    changes seeding state, or its exposure differs from the last one sent by more
    than 1/6 EV. Compare press and release always send.
Q5. All Part 1 and Part 2 tests pass; some Part 2 tests only need their frame
    timestamps advanced, and no assertion is weakened.
Q6. fmt, test, clippy, Node and Biome pass.
Q7. **On the Pi, at night** (needs a deploy): over 40 s of recorded preview,
    control revisions ≪ 86 and the gain spread ≪ 0.40 EV, with no visible colour
    pumping.

### Test plan (written before implementation)

- Rust: `preview_learning_is_time_based` (Q1),
  `preview_loop_with_gain_dependent_metering_settles` (Q2, including the
  old-behaviour guard), and updated Part 1/2 preview tests (Q5).
- Node: `previewNeedsUpdate` (Q4). The event split (Q3) is covered by code
  review and the on-Pi recording (Q7): it is browser wiring without a pure seam.
- Pi: repeat the 40 s MJPEG recording and analysis after an approved deploy
  (Q7).

### Part 3 implementation

- `src/exposure_ramp.rs`: `PREVIEW_LEARNING_TIME_CONSTANT_S = 5.0`.
  `observe_preview` blends the scene and clip estimates by `1 − e^(−Δt/τ)`, with Δt
  measured from `state.updated_at` and clamped to 0 or more. `observe`
  (captures) is unchanged.
- `src/web/scheduled-exposure.js`: `previewNeedsUpdate` with
  `PREVIEW_HYSTERESIS_EV = 1/6`. `previewOverride` records the source it
  sends (`lastSentSource`). `onStatus` re-requests the stream only when
  `previewNeedsUpdate` says so, through the new preview-only event.
  `setComparing` uses the same event. The unused `lastPlanKey` is removed.
- `src/web/app.js`: a `scheduled-exposure-preview-change` listener
  (`controlRevision += 1; schedulePreviewUpdate()`, with no `refreshStatus`).
- Tests: `preview_learning_is_time_based`,
  `preview_loop_with_gain_dependent_metering_settles` (new).
  `preview_frames_seed_the_ramp_and_keep_the_capture_step_anchor`,
  `preview_frames_leave_the_guard_alone` and the Part 2 `preview_loop` helper
  now advance time explicitly (1 s, 2 s, and one iteration per 3 s poll).
  Their assertions use the time-based blend; none were loosened. Node:
  `previewNeedsUpdate`.
- Docs: `docs/optic-daemon-exposure-ramping.md` gets the §5.7 learning formula,
  a §11 bullet (which also drops a stale "eases white balance"), and a new §11.1.

Test mistake found on the first run: an assertion claimed that 700 → 600 ms (0.22 EV) is
below the 1/6 EV hysteresis. The test was wrong, so it now checks 650 → 600 ms
(0.12 EV, no update) and 700 → 600 ms (update).

### Part 3 validation (Mac)

| Check | Result |
|---|---|
| `cargo fmt --check` | pass |
| `cargo test --locked` | pass: 264 (`exposure_ramp` 38) |
| `cargo clippy --locked --all-targets -- -D warnings` | pass |
| `node --test tests/web/*.test.js` | pass: 30 |
| Biome 2.5.14 `ci` | pass: 13 files |
| Q7 on the Pi | **not run**: needs a deploy |

Simulated loop (the measured bias of 1.2 EV per EV, 8 fps, 3 s poll, 40 polls;
numbers from a temporary `eprintln!`, removed afterwards):

| Learning | Peak-to-peak swing, last 10 polls |
|---|---|
| Old: per frame, weight 0.5 | **0.667 EV**, a sustained limit cycle alternating 21.19 ↔ 21.86 |
| New: time-based, τ = 5 s | **0.000 EV**, settled at the correct exposure |

### Part 3 limitations

- The per-gain shadow colour itself is not fixed. It is sensor and ISP rendering at
  high analogue gain, not isolated (a fixed-gain test at 5× and 7× would
  isolate it). It now changes only when the exposure really changes.
- While a preview runs, its frames still teach the scene estimate that the next
  scheduled capture plans from, and the high-gain preview metering is biased
  relative to stills at gain 1. The size of that bias on the timelapse is not
  measured. It predates this work (§11), but Part 3 makes it visible.
- The event split (Q3) has no unit test. It is verified by review and needs
  the Q7 recording.

### Part 3 on the Pi (2026-09-23, user-approved "deploy now + re-record")

**Deploy.** `scripts/build-deploy-optic-daemon.sh`, exit 0. On-Pi: 259 tests
in the main binary, clippy, release build, `SUCCESS`. The daemon was down from 23:49:53 to
23:52:45. The served `scheduled-exposure.js` contains `previewNeedsUpdate`.

**Q7 recording.** The user reloaded a visible dashboard, with Scheduled exposure on and
the preview started. 60 s of MJPEG was recorded as a read-only viewer and analysed
with the same script as the baseline (scratchpad `stream_stats.py`):

| | Before (21:56, 40 s) | After (23:53, 60 s) |
|---|---|---|
| Control revisions | 86 | 2 (one of them the stream restart after a capture) |
| Distinct exposures while live | 40 (gain 5.22–6.87, 0.40 EV) | **1** (119 ms × 12.19 for all 196 live frames) |
| Frame R/G | 1.08–1.41, sd 0.092 | 1.18–1.22, **sd 0.010** |
| Frame B/G | sd 0.025 | sd 0.005 |

The colour pumping is gone while the preview is live. The preview ran 119 ms × 12.19 ≈ 1.45 s,
which matches the plan (3.44 s) at the guard's target (−1.29 EV).

**New finding: preview frame rate (user: "preview frame rate should be
consistent").** The recording's second segment was two frames at 3,474,267 µs
× 1.0 (sequence reset to 0). The journal (23:53–23:56) shows why:

- Every scheduled capture runs `stop_existing_preview`, then a still pipeline
  of 11 warm-up frames at the capture's exposure: `warmup_and_capture` took
  25,072 ms and 22,758 ms at about 3.5 s night frames. The preview gets **no frames for about
  23–25 s every minute**.
- The preview pipeline then restarts, and its first frames still carry the
  still's exposure (3.47 s): libcamera applies new controls a few frames late, so there are
  about 7 more seconds at about 0.3 fps.
- At a 1-minute interval with a night frame of about 3.5 s, the preview is live for only about half of
  each minute. This predates Parts 1–3 (captures always stopped the preview).
  It is more visible tonight because the night exposure is long (at 20:51, 0.84 s:
  6.6 s per capture).
- The user also questioned "re-request the stream". An exposure-only change takes
  `ReconfigureStream`'s controls-only path (`native_camera.rs`: settings and
  revision updated, no pipeline restart), so it costs no frames. The worklog
  and design text are corrected to say "exposure update".

Candidate fixes (not implemented; design doc §9 already lists the first two
as follow-ups): pass the preview controls to `camera.start()` so the first
frames after a capture use the preview exposure; shorten the 11-frame warm-up
for fully manual stills (needs an on-Pi test); longer term, a combined preview and still
configuration that never stops the preview.

## Part 1 observed on hardware (2026-09-23 23:55–23:58 PDT, journal, read-only)

The first night with the guard deployed (branch build), AutoRamp defaults, 1%
budget, with the room lights off as on 2026-09-22:

| Time | Clipped (daemon meter) | Pull | Offset `H` |
|---|---|---|---|
| 23:55:23 | 2.65% | 1.0 EV (second over-budget frame, capped) | −1.00 EV |
| 23:56:11 | 1.12% | 0.17 EV | −1.17 EV |
| 23:57:10 | 1.005% | 0.008 EV | −1.18 EV |
| 23:58:11 | 1.03% | 0.008 EV | −1.19 EV |

The captured exposure went from 3.47 s to 3.13 s (the step-limited ramp) and then 1.46 s
(the guard's widened downward step). This matches the replay's prediction (settled about
1.44 EV darker at about 1%), with no oscillation. Frames sitting just above the budget make
tiny pulls (0.008 EV per frame) until clipping drops below 1%; this
self-limits by design (hold band). Hardware-observed for 4 frames only: the
overnight comparison is still pending.

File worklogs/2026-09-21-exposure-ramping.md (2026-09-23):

# Dated Worklog: 2026-09-21 - Exposure Ramping for Scheduled Captures

Status: **Part 1 (ramp engine): deployed 2026-09-22 and partly
hardware-validated** (4 frames: seed, shutter-first jump, 1/3 EV steps,
manual WB; night convergence not observed). **Part 2 (dashboard UX
redesign): implemented and tested on the Mac (unit, node and browser
checks); not deployed, not hardware-verified.** Awaiting user acceptance. The test plan was written before any `src/` edit.

Design: `docs/optic-daemon-exposure-ramping.md`.

## Objective

Smooth day-to-night ("Holy Grail") exposure for scheduled timelapse captures:
meter each captured frame, follow a sun-elevation target, limit per-frame
exposure change, put exposure into shutter before gain, and replace per-frame
AWB with eased white balance.

## Decisions (user, 2026-09-21, via question tool)

- Max shutter: keep the 5 s cap.
- Night look: brightened night (day level to +6°, 2 EV darker by −18°).
- Scope: **global only**, one exposure mode for all scheduled captures. The
  user first leaned towards per-rule ramps, then asked how merged rule
  captures could work and how professional controllers do it. After that
  discussion they chose global only, with no per-rule presets. The original
  task's "per-rule exposure presets" item is therefore dropped. The Scheduler
  page gets a global "Scheduled exposure" card instead.
- WB: eased grey-world, seeded from AWB.
- Metering: trimmed log-mean luma.

## Acceptance Criteria

1. `ScheduleConfig.exposure` defaults to `Dashboard`. Old `config.json`
   files load unchanged, and scheduled captures in `Dashboard` mode build
   exactly the same `CaptureRequest` as before.
2. In `AutoRamp` mode, the first scheduled capture (or the first after a gap
   of more than 30 min) is an auto-exposure/AWB seed. Every later capture
   uses manual shutter, gain and colour gains from the ramp.
3. Consecutive ramped frames differ by at most `max_step_ev` in planned
   exposure (except the first frame after a seed), and colour gains change
   by at most `wb_max_step_pct` per frame.
4. Exposure goes into shutter first and gain only once the shutter is at
   its effective maximum. When brightening, gain drops back to 1 before
   the shutter shortens.
5. The target follows sun elevation: day level at ≥ +6°, day − `night_drop_ev`
   at ≤ −18°, and monotonic in between. Without a station it stays at the
   day level.
6. The shutter never exceeds `min(max_shutter_us, interval budget)`, and the
   5 s validation cap is unchanged.
7. On a synthetic sunset (scene brightness falling about 17 EV over the
   sun-elevation range), the simulated ramp converges without oscillating
   and ends within 0.5 EV of the night target, unless it is limited by
   max shutter × max gain.
8. The metering result is independent of image content ordering, ignores
   the extreme 2% tails, and gives the same answer for a stride larger
   than the width.
9. `POST /api/schedule/preview` rejects out-of-range exposure settings
   (422). The Scheduler page stages and saves the exposure mode with the
   rules, and shows the live ramp status.
10. `cargo fmt --check`, `cargo test`, `cargo clippy --all-targets -D warnings`
    pass on the Mac. Linux-only `native_camera.rs` code compiles on the Pi
    or build VM (only with the user's approval if it runs on the Pi).

## Test Plan (written before implementation)

### Host unit tests (`cargo test`, Mac)

`src/exposure_ramp.rs`:
- `meter_*`: a uniform grey frame measures its own linear luminance; a frame
  with 1% pure-white and 1% pure-black pixels measures the same as without
  them (trim); padded stride equals the unpadded result; a colour-cast frame
  gives grey-world ratios > 1 in the right channel; an all-black frame has
  no usable grey-world estimate.
- `target_bias_ev`: the values at +10°, +6°, −6°, −18°, −30°, and
  monotonicity across the curve; `None` elevation → day level.
- `split_exposure`: shutter-first, gain-last; the gain ceiling holds; a
  product below the minimum clamps to the minimum shutter at gain 1.
- `plan`/`observe`: no state → seed; stale state (> 30 min) → seed; the first
  frame after a seed is unlimited; later frames are step-limited; a
  simulated sunset converges (criterion 7) with monotonic exposure;
  smoothing damps a single bright outlier frame (a car's headlights);
  WB converges toward neutral with ≤ 3% steps and is held on dark frames.
- `max_shutter_for_gap`: 30 s → about 2.0 s, 1 min → about 4.2 s, no gap →
  no cap, tiny gap → min shutter.
- `RampSettings::validate` rejects each out-of-range field; `sanitized`
  clamps.

`src/camera.rs`: `colour_gains` defaults to `None`; old settings JSON
still deserializes; out-of-range gains are rejected.

`src/optic_scheduler.rs`: `ScheduleConfig` without `exposure` → `Dashboard`;
an `AutoRamp` JSON round trip; the Dashboard request equals the committed
settings (regression for criterion 1); a ramped request carries the plan's
shutter, gain and colour gains.

### Build checks

- `cargo fmt --check`, `cargo test`, `cargo clippy --all-targets -- -D warnings`
  on the Mac (non-Linux: `native_camera` compiles to its stub).
- The Linux compile of `native_camera.rs` (metering hook, `ColourGains`
  control) happens in the build VM (`vmpi` skill) if available, otherwise
  unverified. The Pi is used only with the user's approval.

### Browser check

- Serve the page against a local daemon if feasible on the Mac, or check
  the JS syntax with `node --check`. Load the Scheduler page and switch the
  mode; the card fields show and hide; staging sends `exposure`.

### Hardware (only with user approval; not part of this session unless approved)

- Deploy and set `AutoRamp` with a short interval rule. Check that the
  first frame is a seed, then manual frames with `colour_gains` in the
  capture log. Observe a real sunset: no visible flicker; the shutter
  rises to its cap before gain rises.

## Files This Track Owns

`src/camera.rs`, `src/native_camera.rs`, `src/optic_scheduler.rs`,
`src/ephemeris.rs` (read only), `src/exposure_ramp.rs` (new),
`src/web/scheduler.html`, `src/web/scheduler.js`,
`docs/optic-daemon-exposure-ramping.md`, and the changed sections of
`docs/optic-daemon-scheduler.md` and `docs/optic-daemon-camera.md`.

### Planned edits outside the owned files (merge-conflict risk)

- `src/main.rs`: `mod exposure_ramp;` (one line).
- `src/web.rs`: `SchedulePreviewRequest` gains an optional `exposure` field,
  validated and staged (about 10 lines). Without this, the Scheduler page
  cannot stage the setting.
- `src/optic_capture_log.rs`: the test helper builds a `CaptureResult`
  literal and needs the new `exposure: None` field (one line, test only).
- `src/web/styles.css`: one small block appended at the end.

## Implementation

- `src/exposure_ramp.rs` (new): `ScheduleExposure` {Dashboard | AutoRamp},
  `RampSettings` (`validate`, `sanitized`), `meter_yuv420`,
  `target_bias_ev`, `split_exposure`, `max_shutter_for_gap`, `plan`,
  `observe` and the eased grey-world WB. Pure, with 21 unit tests.
- `src/camera.rs`: `CameraSettings.colour_gains: Option<[f32; 2]>` (validated
  0.5..8); shared limit constants (`MIN/MAX_SHUTTER_US`, `MIN/MAX_GAIN`,
  `COLOUR_GAIN_MIN/MAX`) now used by `validate` (same ranges and messages);
  `STILL_CAPTURE_FRAMES = 11`; `CaptureResult.exposure: Option<CaptureExposure>`.
- `src/native_camera.rs` (Linux only): `apply_controls` sets
  `AwbEnable(false)` + `ColourGains` when `colour_gains` is `Some`, and
  otherwise behaves as before. The output frame's `ExposureTime`,
  `AnalogueGain` and `ColourGains` metadata go into `CaptureExposure`. The
  frame is metered after capture, with a new `stage="meter"` perf log line.
- `src/optic_scheduler.rs`: `ScheduleConfig.exposure`; `build_capture_request`
  (Dashboard is unchanged; Seed = auto shutter/gain/AWB; Manual = the plan's
  shutter/gain/gains); `plan_ramp_shot`; the actor keeps one in-memory
  `RampState` and passes the gap to the next shot; `SchedulerStatus.exposure:
  Option<RampSnapshot>`; the capture log records the ramped settings actually
  requested.
- `src/web/scheduler.html`, `scheduler.js`: a "Scheduled exposure" card
  (mode plus 8 limits, staged with the rules, and a live "Last ramped frame"
  readout).
- Outside the owned files (merge-conflict risk, all small):
  - `src/main.rs`: `mod exposure_ramp;`.
  - `src/web.rs`: `SchedulePreviewRequest.exposure: Option<_>`, validated
    (422) and staged only when present, so older clients don't reset it.
  - `src/optic_capture_log.rs` (test helper, `exposure: None`) and
    `src/optic_alerts.rs` (test literal, `..ScheduleConfig::default()`):
    needed to compile the tests after the new struct fields. Test code only.
  - `src/web/styles.css`: 7 lines appended at the end, plus the missing
    final newline.
- Docs: `docs/optic-daemon-exposure-ramping.md` (new);
  `docs/optic-daemon-scheduler.md` (header note on Decision #3, `ScheduleConfig`
  sketch, §5 exposure bullet); `docs/optic-daemon-camera.md` (new §4.1.1).

## Validation

Mac (darwin, host target; `native_camera.rs` compiles to its non-Linux stub):

| Check | Result |
|---|---|
| `cargo fmt --check` | pass |
| `cargo test` | pass, 197 tests (27 new: 21 in `exposure_ramp`, 1 in `camera`, 5 in `optic_scheduler`) |
| `cargo clippy --all-targets -- -D warnings` | pass |
| `npx @biomejs/biome@2.5.14 ci` (CI's pinned version) | pass after `biome format` wrapped one line |
| `node --check src/web/scheduler.js` | pass |

Local daemon (`target/debug/optic-daemon`, `127.0.0.1:18000`, isolated
`HOME`/cache in the session scratchpad, sync disabled, no camera):

- `GET /api/status` on a fresh config → `schedule.exposure = {"mode":"Dashboard"}`,
  status `exposure: null` (criterion 1).
- `POST /api/schedule/preview` with `max_gain: 20` → 422 `invalid scheduled
  exposure: max gain must be between 1 and 16`; with `max_gain: 4` → 200 and
  staged with defaults filled; a body without `exposure` → 200 and the staged
  exposure kept (criterion 9).
- Scheduler page in Chrome: the staged AutoRamp values load into the card;
  editing max shutter to 2 s and gain to 6 stages `2000000`/`6` and enables
  Save rules; a blank field shows a client notice; `day bias 5` shows the
  backend 422 message; switching to Dashboard hides the fields and stages
  `{"mode":"Dashboard"}`; the readout renders ramped and seed snapshots.
- Bug found and fixed: switching to Dashboard and back reset edited limits to
  their defaults (`renderExposure` rewrote every input). Inputs are now only
  overwritten in AutoRamp mode or when empty. Re-tested: values survive the
  toggle (`2`, `6`).
- Bug found and fixed by the sunset simulation test: `split_exposure` gave
  gain ≈ 1.0004 below the shutter ceiling (the shutter rounded down). Gain is
  now exactly 1 until the shutter is at its ceiling (regression test added).
- End to end: committed AutoRamp with a Vancouver station and a 60 s interval
  rule, then resumed. At 06:47:00Z the actor planned a seed, with
  `sun_elevation_deg: -37.66`, `target_bias_ev: -2.0`, `max_shutter_us:
  4227272` (the 60 s gap budget). The capture failed (`camera actor is
  unavailable`, expected on the Mac) and the ramp state stayed unset. The
  scheduler was paused and the daemon stopped afterwards.

Pi, compile-only (user-approved 2026-09-22; no install, no service change,
daemon stayed `active`). The vmpi build VM can't be used: it doesn't mount
this worktree and has no libcamera sysroot.
- The worktree source was uploaded to `~/.local/src/optic-exposure-ramping-check`
  and built into a separate `~/.cache/optic-exposure-ramping-target` (seeded
  from `optic-capture-latency-target`) with the deploy script's sysroot
  environment, `stable` toolchain (1.98.1 not installed; the deploy
  script's own fallback), `CARGO_BUILD_JOBS=2`, `nice -n 10`.
- The first two launches did nothing: the script uploaded empty (a trailing `&`
  backgrounded the `cat > file` too). Fixed with an `scp` upload and a
  `setsid` launch, and recorded in `AGENTS.md`. `src/optic_scheduler.rs` was re-synced
  before the run, so the Pi built the final source.

| Pi step | Result |
|---|---|
| `cargo fmt --all -- --check` | pass |
| `cargo clippy --locked --all-targets -- -D warnings` | pass (Linux `native_camera.rs` compiles: `AwbEnable(false)` + `ColourGains`, metadata capture, meter hook) |
| `cargo test --locked --all-targets --no-run` | pass |
| `cargo test ... exposure_ramp` | 21 passed |
| `cargo test ... native_camera::` | 5 passed |
| `cargo test ... camera::tests::colour_gains` | 1 passed |

Rebase onto `origin/main` (2026-09-22, after PRs #13 focus-tools, #14
pi-services-audit and #15 digest-heartbeat merged):
- Conflicts in `CLAUDE.md` (Environment and Tooling Constraints bullets) and
  `src/web/styles.css` (focus-tools block): both were appends at the end.
  Both sides kept, with this track's lines after upstream's.
- `src/optic_digest.rs` (new upstream, test module only): its
  `ScheduleConfig` literal gets `..ScheduleConfig::default()`. This is outside
  the track, and is needed to compile the tests.
- Re-run on the rebased tree (Mac): `cargo fmt --check` pass;
  `cargo test` 234 passed; `cargo clippy --all-targets -- -D warnings` pass;
  Biome 2.5.14 `ci` pass (12 files); `node --test tests/web/*.test.js` 13
  passed. The earlier Pi compile check ran on the pre-rebase source.

Not deployed, because another track was on the Pi: before the planned deploy
on 2026-09-22, the Pi was running the digest-heartbeat build (committed
`config.json` has a top-level `notifications` block, and `digest_state.json`
had been written minutes earlier). A preview stream was open, and
`preview_config.json` held uncommitted staged edits. The pre-rebase branch had
no `notifications` field, so a deploy plus a test commit would have dropped
that config. The rebased branch includes it. The deploy was put on hold
until the user confirms.

### Deploy and hardware test (2026-09-22, user-approved)

- The user discarded the pending staged dashboard edit first. Then
  `./scripts/build-deploy-optic-daemon.sh` (rebased branch = main + ramp)
  ran and exited 0: fmt, 232 tests on the Pi (service stopped), clippy
  `-D warnings`, release build, install with rollback. The service is active.
  `notifications` config was kept and applied; the exposure mode defaulted to
  Dashboard.
- The test committed `{"mode":"AutoRamp"}` (defaults; station, rules and
  notifications resent unchanged) and resumed the existing `every1min` rule
  (60 s, so the budget capped the shutter at 4,227,272 µs). Night, sun ≈ −40°,
  target −2 EV (0.045).

| Frame (UTC) | Kind | Shutter (metadata) | Gain | ColourGains R/B | Luminance |
|---|---|---|---|---|---|
| 08:30:02 | seed (AE/AWB) | 66,654 µs | 15.52 | 2.648 / 1.827 | 0.0096 |
| 08:31:32 | ramped | 4,226,589 µs | 1.145 | 2.634 / 1.823 | 0.089 |
| 08:32:46 | ramped | 3,843,022 µs | 1.000 | 2.662 / 1.827 | 0.066 |
| 08:33:36 | ramped | 3,050,132 µs | 1.000 | 2.684 / 1.828 | 0.0156 |

Observed on hardware:
- A manual 4.2 s shutter is honoured; the previous tested maximum was 1 s.
- `AwbEnable(false)` + `ColourGains` holds on the output frame. The easing
  moved at most 1.05% per frame.
- The first ramped frame after the seed jumped straight to shutter-first
  (the seed's AE used gain 15.5). Later steps were exactly −1/3 EV, with gain
  taken out before the shutter was shortened.
- Captures completed within the 48 s budget (the slowest took 45.5 s; the
  11-frame warmup dominates).
- The loop overshot by 1 EV after the seed jump (0.089 against 0.045): the
  shadow tone curve is steeper than the γ 2.2 model. The loop was correcting
  as designed.
- Frame 4 metered 2.1 EV darker from a 1/3 EV cut. This is most likely a scene
  change (a light going off at 01:33 local); unconfirmed, because the frames
  had already synced off the Pi.
- **Not observed:** night steady state and convergence. Someone (not this
  session) paused the scheduler during frame 4. `schedule_run_state.json` was
  written at 08:33:36, the second the capture finished, because commands wait
  while a capture is in progress.
- Finding: during long ramped captures, Pause/Resume replies wait for the
  capture to finish (up to about 45 s at night). This comes from the existing
  actor design, and is now visible.
- Finding: the Scheduler card rounds `max_step_ev` for display, and
  re-staging wrote 0.33 back (seen staged on the Pi). To be fixed in the
  dashboard redesign.
- Restored afterwards: exposure mode Dashboard committed (a staged-only
  `max_step_ev` diff was superseded), the scheduler left Paused as the pauser
  wanted, and rules, station, notifications and gain 11.8 unchanged.

Not run on the Pi, on purpose: the full `cargo test`. `optic_camera.rs:290`
and `optic_scheduler.rs:2138` spawn the real camera on Linux, and would contend
with the running daemon.

Not run: deployment, hardware captures, sunset observation (need user
approval).

## Limitations / Next Steps

- **Unverified on hardware** (it now compiles on Linux). Unknowns: whether `AwbEnable(false)`
  + `ColourGains` is honoured on the output frame after the 11-frame warmup;
  what the real metering cost is on 12 MP frames (expected a few ms); and
  whether γ 2.2 linearization is close enough to the Pi's tone curve (the
  loop is closed, so bias only shifts the steady-state brightness, which
  `day_bias_ev` can offset).
- Long shutters: every capture still waits about 11 frames. The interval
  budget caps a 30 s night interval at about a 2 s shutter. Reducing warmup
  for fully manual frames, and passing the still controls to `camera.start()`,
  needs an on-Pi test.
- Grey-world pulls vivid sunsets and sodium-lit scenes toward neutral
  (slowly, at 3% per frame). The DNG keeps the raw data.
- Ramp state is in memory only; a restart reseeds (by design).
- The original task item "per-rule exposure presets" was dropped by the
  user's decision (global only).
- `Cargo.toml` version not bumped (it is bumped at merge time).
- Pi leftovers from the compile check (not deleted without approval):
  `~/.local/src/optic-exposure-ramping-check`,
  `~/.cache/optic-exposure-ramping-target` (1.5 GB),
  `~/.cache/optic-exposure-ramping-check.{sh,log}`.

## User Verification Steps (after approval to build and deploy)

1. Build and deploy (`./scripts/build-deploy-optic-daemon.sh`), then on the
   Scheduler page choose Auto-ramp, keep the defaults, and Save rules.
2. With a rule of 30–60 s through a sunset: check that "Last ramped frame" shows a
   seed first, then manual frames; that the shutter rises to its cap before the
   gain rises above 1; and that WB changes slowly.
3. Build a timelapse from the frames and check for flicker, and that night
   is darker than day but not black.

## Part 2: Dashboard UX Redesign (2026-09-22) — plan written before code

### Request (user, 2026-09-22)

The Scheduler-page card is "too professional", not intuitive, and can't be
verified visually. Move scheduled exposure onto the dashboard's camera
controls: a **Scheduled exposure** toggle below Shutter. When it's on, show
the ramp settings, make the manual exposure fields read-only, and have them
show the live values calculated from the ramp, with a subtle colour hint that
they change over time. The user approved adding this to PR #16, then went
AFK: "please use your best judgement going forward". Judgement calls are
listed below. No new deploy or Pi use happens without the user.

### Design (best judgement, recorded for the user's review)

1. **Toggle = `ScheduleConfig.exposure.mode`.** It is staged through a new
   `POST /api/schedule/exposure` (mirrors `/api/config/save-dng`) and
   saved or discarded by the dashboard's existing Save Settings / Discard
   Changes.
2. **Live plan from the server.** `GET /api/status` gains `exposure_plan`,
   computed on each poll from the staged-or-committed schedule, the
   scheduler's in-memory ramp state, and the sun elevation *now*: the next
   planned shutter, gain and colour gains (or `seeding: true`), target
   bias, sun elevation, and shutter cap. It is `null` in Dashboard mode. The
   ramp only learns from captured frames, so the values drift with the sun
   target between frames and jump when a frame is observed.
3. **Locked fields show the plan.** With the toggle on, the Shutter and Gain
   inputs (and White balance) are disabled and show the planned values in an
   amber "ramp" style. A short pulse plays whenever the values change. While
   seeding, they read "Auto (seeding)". The user's manual values are kept
   in the inputs' staged settings and come back when the toggle goes off.
4. **Brightness-equivalent live preview.** The stream request gains an
   optional, never-staged `exposure_override`. With the toggle on, the
   preview uses the plan's total exposure with the shutter clamped to the
   preview frame time and the rest moved into gain (max 16), plus the plan's
   colour gains. The preview then shows the next frame's brightness and
   colour at preview frame rate (noisier). A seeding plan previews with auto
   exposure and AWB, which is what the seed frame will use.
   `reconfigure_stream` stages only `settings`, so the override never
   reaches the saved config. Manual "Capture & transfer" keeps using the
   manual settings, unchanged.
5. **Fewer knobs.** Night look (a slider from dark to bright, mapped to
   `night_drop_ev` 4…0), Max shutter, and Max gain (noise limit). The other
   five go in a collapsed "Advanced". Each input writes only its own field,
   which fixes the Scheduler card's `max_step_ev` rounding write-back.
6. **The Scheduler page card becomes read-only.** It shows the mode, the last
   ramped frame, and "Configure on the Dashboard". `scheduler.js` stops
   sending `exposure`, so it can't overwrite the dashboard's value.
7. New UI code lives in `src/web/scheduled-exposure.js` (the focus-tools
   pattern: pure functions tested with `node --test`). `app.js` only gets
   small hooks: `streamRequest` and `refreshStatus`, plus excluding the new
   inputs from the generic control listener.

### Acceptance criteria (Part 2)

A1. Toggling on the dashboard stages `{"mode":"AutoRamp",…}`, and Save
    Settings commits it. Toggling off stages `Dashboard`.
A2. With the toggle on, the Shutter, Gain and White balance inputs are
    disabled and show `exposure_plan` values (or "Auto (seeding)"),
    refreshed with every status poll, with a visible hint when a value
    changes.
A3. With the toggle on, the preview request carries a brightness-equivalent
    `exposure_override`; the staged `settings` keep the manual values.
    Toggling off removes the override and restores the manual fields.
A4. `exposure_plan` is `null` in Dashboard mode; `seeding: true` with no
    ramp state; otherwise it matches `exposure_ramp::plan` for now.
A5. The three simple knobs plus Advanced stage only the field that was
    edited (no rounding write-back).
A6. The Scheduler page shows ramp status read-only and never sends
    `exposure`.
A7. All existing checks pass (fmt, test, clippy, Biome, node web tests), plus
    new Rust and node tests.

### Test plan (Part 2)

- Rust: `live_exposure_plan` is None for Dashboard, seeding without state,
  and equal to `plan()` with a state; `StreamRequest::effective_settings`
  applies the override (seed → auto/AWB auto; manual → shutter/gain/gains)
  and validates; `exposure_override` defaults to None, so old request JSON
  still parses; `POST /api/schedule/exposure` validation (reuses
  `RampSettings::validate`); the `web.rs` asset test checks the new element
  IDs.
- Node: `previewEquivalent` (a clamp to frame time moves exposure into gain;
  capped at 16; seeding → auto), the night-look mapping in both directions,
  shutter formatting.
- Local daemon plus Chrome on the Mac (no camera): toggle staging, locked
  fields, Advanced, Save/Discard, and the Scheduler page read-only card. The
  preview override on real frames needs the Pi, so it is left for the user.

### Implementation (Part 2)

- `src/camera.rs`: `StreamRequest.exposure_override: Option<ExposureOverride>`
  (`#[serde(default)]`, so older clients still parse); `effective_settings()`
  (override applied; no colour gains → AWB auto); `validate()` checks the
  effective settings.
- `src/native_camera.rs`: preview start/reconfigure uses
  `request.effective_settings()`. Still capture is unchanged.
- `src/optic_scheduler.rs`: `SchedulerStatus.ramp_state` (`#[serde(skip)]`,
  published after each capture); `LiveExposurePlan` and
  `live_exposure_plan(schedule, ramp_state, now)`, which reuses
  `exposure_ramp::plan`, the sun elevation now, and the interval budget
  (6 h lookahead).
- `src/web.rs` (outside the owned files): `StatusResponse.exposure_plan`;
  `POST /api/schedule/exposure` (staging like `stage_save_dng`, 422 via
  `RampSettings::validate`); a wiring test like focus-tools'.
- `src/web/scheduled-exposure.js` (new): the toggle, the three simple
  controls plus Advanced, the locked amber live values with a pulse, the
  caption (target, sun, shutter cap, last learned, and preview shortfall),
  and the preview override. The pure functions are exported for Node.
- `src/web/index.html`, `src/web/app.js` (outside the task brief's owned
  files; focus-tools, their owner, merged in #13): the toggle block below
  Shutter and the live-value outputs; `app.js` adds 28 lines (the override in
  `streamRequest`, `applyConfig`/`onStatus` hooks, a
  `scheduled-exposure-change` listener, and the manual-control selector
  excluding `data-ramp-input`).
- `src/web/scheduler.{html,js}`: the card is read-only (mode pill, last
  ramped frame, link to the Dashboard); `exposure` is no longer sent.
- `src/web/styles.css`: the unused card grid rules were removed and a
  dashboard block appended. Gain is pinned full-width, because the new block
  shifts the existing `nth-last-child(-n+3)` span rule.
  `prefers-reduced-motion` disables the pulse.
- `biome.json`: added `src/web/scheduled-exposure.js` (outside the owned
  files). `tests/web/scheduled-exposure.test.js` (new).
- Docs: `docs/optic-daemon-exposure-ramping.md` §4/§7/§10;
  `docs/optic-daemon.md` API list (`exposure_plan`,
  `/api/schedule/exposure`, `exposure_override`).

### Validation (Part 2, Mac)

| Check | Result |
|---|---|
| `cargo fmt --check` | pass |
| `cargo test` | 238 passed (+4: override parsing/effective settings, live plan ×2, dashboard wiring) |
| `cargo clippy --all-targets -- -D warnings` | pass |
| Biome 2.5.14 `ci` (13 files) | pass (`biome format` applied to the touched web files) |
| `node --test tests/web/*.test.js` | 22 passed (9 new) |

Local daemon (no camera, Vancouver station, 60 s rule) in Chrome:
- `POST /api/schedule/exposure` with `night_drop_ev: 9` → 422 `night
  darkening must be between 0 and 6 EV`.
- Toggle on → staged `AutoRamp`, Save enabled; `exposure_plan` = seeding,
  sun −39.4°, target −2.0 EV, cap 4,227,272 µs (A1, A4). Shutter, Gain and
  White balance hidden/disabled, showing "Auto (seeding)" in amber
  (A2). `settings()` still returns the manual values; the stream override is
  `{0, 0, null}` (auto, like the seed) (A3).
- Simulated plan 3.84 s → 3.05 s: the live fields read "3.8 s" / "1.00×" /
  "Eased · R 2.63 / B 1.82" and then "3.1 s" with the pulse class; the
  override is 118,750 µs × 16 (8 FPS, caption "preview ≈ 1.0 EV darker"),
  and 475,000 µs × 8.09 for the 2 FPS Master Archive preview; two change
  events.
- Night look → Bright staged only `night_drop_ev: 2 → 0` (A5; the rounding
  write-back is fixed).
- Discard reverts the toggle and fields to the committed mode and leaves
  nothing staged; Save commits `AutoRamp` (A1).
- Scheduler page: an "Auto-ramp" pill and a link to `/`, with no editable
  inputs; staging rules leaves `exposure` unchanged (A6).
- Side observation (not from this change): in one run, `config_staged`
  read `true` right after Discard. This matches the existing behaviour of
  `start_stream`/`reconfigure_stream` staging the current camera `settings`
  whenever the preview (re)starts. A later reproduction staged nothing.

GitHub CI on PR #16 head `1db6a39`: Detect changed scope pass, Biome
pass, **Rust (Debian 13 arm64) pass** (Linux build and tests, including the
`native_camera.rs` preview-override path), Timelapse tool skipped (not
touched).

Not verified (needs the Pi and user approval, so not done while the user
is away): the preview override on real frames, and whether the preview's
brightness matches the scheduled frames.

### Limitations / next steps (Part 2)

- At night the preview can't fully match the frame: an 8 FPS preview tops
  out at about 119 ms × 16 gain, so the caption shows the shortfall
  (≈ 1 EV for a 4 s frame). Master Archive's 2 FPS preview gets 8× more
  headroom.
- The live plan only changes when a scheduled frame is observed, or when the
  sun target drifts. It doesn't learn from the preview.
- Starting a preview with the toggle on uses the override, so another tab
  viewing the preview sees the ramp exposure too. This is intended, since the
  preview is shared.
- Deploying Part 2 and checking it on the camera is left for the user
  (steps below).

### Deploy (Part 2, 2026-09-22, user-requested)

- Pre-flight: the worktree was clean at `aeb0ad9`; no build was running on the
  Pi; nothing was staged; no preview was streaming; the scheduler was paused;
  the mode was Dashboard.
- `./scripts/build-deploy-optic-daemon.sh` exited 0: Biome, fmt, 234
  tests on the Pi, clippy `-D warnings`, release build, install with
  rollback. The service is `active` and the journal shows no warnings since
  the restart.
- Verified live: `/api/status` has `exposure_plan` (`null` in Dashboard
  mode); `/scheduled-exposure.js` is served (200, 10,999 B); the dashboard HTML
  has `#scheduled-exposure`; `POST /api/schedule/exposure` with
  `max_gain: 99` → 422, with nothing staged. Rules, station, notifications
  and gain 11.8 are unchanged; still paused; still Dashboard mode.
- **Deployed, not yet hardware-verified in the UI.** The live preview
  override on real frames is the user's acceptance step below.

### User verification (Part 2)

1. Approve a deploy (`./scripts/build-deploy-optic-daemon.sh`), or merge
   PR #16 and deploy `main`.
2. On the dashboard, turn on **Scheduled exposure**. Shutter, Gain and White
   balance turn amber and read "Auto (seeding)". The preview switches to auto
   exposure. Press **Save Settings**.
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

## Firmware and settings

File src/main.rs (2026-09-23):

mod camera;
mod durable_state;
mod ephemeris;
mod exif;
mod exposure_ramp;
mod native_camera;
#[cfg(target_os = "linux")]
mod native_codec;
mod optic_alerts;
mod optic_camera;
mod optic_capture_log;
mod optic_digest;
mod optic_events;
mod optic_heartbeat;
mod optic_scheduler;
mod optic_sync;
mod system_status;
mod web;

use std::{env, net::SocketAddr, path::PathBuf};

use optic_camera::OpticCamera;
use optic_capture_log::CaptureLog;
use optic_events::{BootInfo, SystemEventKind, SystemEventLog};
use optic_sync::{DataSyncManager, SyncConfig};
use system_status::{SystemStatusReader, WatchedPaths};
use tokio::net::TcpListener;
use tracing::{info, warn};
use tracing_subscriber::EnvFilter;
use web::AppState;

const DEFAULT_BIND: &str = "0.0.0.0:8000";
const DEFAULT_CAPTURE_DIR: &str = "/mnt/capture";
const DEFAULT_SYNC_REMOTE_PORT: u16 = 2222;
const DEFAULT_SYNC_REMOTE_USER: &str = "admin";
// Falls back to the workspace source tree so `cargo run`/`cargo test` hot-reload
// UI edits during local development, where no sibling `web/` directory exists
// next to the debug binary.
const DEV_ASSET_DIR: &str = concat!(env!("CARGO_MANIFEST_DIR"), "/src/web");

#[tokio::main]
async fn main() -> Result<(), Box<dyn std::error::Error>> {
    tracing_subscriber::fmt()
        .with_env_filter(
            EnvFilter::try_from_default_env().unwrap_or_else(|_| EnvFilter::new("info")),
        )
        .with_target(false)
        .compact()
        .init();

    let bind: SocketAddr = env::var("OPTIC_BIND_ADDR")
        .unwrap_or_else(|_| DEFAULT_BIND.to_owned())
        .parse()?;
    let capture_dir = PathBuf::from(
        env::var("OPTIC_CAPTURE_DIR").unwrap_or_else(|_| DEFAULT_CAPTURE_DIR.to_owned()),
    );
    validate_capture_dir(&capture_dir).await?;

    let asset_dir = resolve_web_asset_dir();
    if asset_dir.is_dir() {
        info!(asset_dir = %asset_dir.display(), "serving web assets from disk");
    } else {
        warn!(
            asset_dir = %asset_dir.display(),
            "web asset directory does not exist; the dashboard will return errors until it is present"
        );
    }

    let camera = OpticCamera::spawn_native();
    let sensor = camera.probe().await;
    if let Some(sensor) = &sensor {
        info!(sensor, "camera detected");
    } else {
        warn!("no IMX477 camera detected; the dashboard will remain available");
    }

    let sync_config = resolve_sync_config();
    if let Some(config) = &sync_config {
        info!(
            remote = format!(
                "{}@{}:{}",
                config.remote_user, config.remote_host, config.remote_port
            ),
            "optic_sync configured"
        );
    } else {
        info!("optic_sync disabled: set OPTIC_SYNC_REMOTE_HOST to enable capture transfer");
    }
    let sync = DataSyncManager::spawn(sync_config, capture_dir.clone());

    let capture_log_db_path = resolve_capture_log_db_path();
    let capture_log = match CaptureLog::open(&capture_log_db_path, capture_dir.clone()) {
        Ok(log) => {
            info!(path = %capture_log_db_path.display(), "capture history log ready");
            Some(log)
        }
        Err(error) => {
            warn!(
                %error,
                path = %capture_log_db_path.display(),
                "capture history log unavailable; captures will not be recorded to history"
            );
            None
        }
    };

    let state_dir = capture_log_db_path
        .parent()
        .map(PathBuf::from)
        .unwrap_or_else(|| capture_log_db_path.clone());
    // Boot/reboot/shutdown and daemon start/stop history
    // (docs/optic-daemon-system-events.md). Its own database next to
    // history.db, so it never contends with capture writes.
    let events_db_path = state_dir.join("events.db");
    let events = match SystemEventLog::open(&events_db_path, BootInfo::read_host()) {
        Ok(events) => {
            events.record_startup(env!("CARGO_PKG_VERSION")).await;
            info!(path = %events_db_path.display(), "system event log ready");
            Some(events)
        }
        Err(error) => {
            warn!(
                %error,
                path = %events_db_path.display(),
                "system event log unavailable; boot and shutdown events will not be recorded"
            );
            None
        }
    };

    let system_status = SystemStatusReader::new(WatchedPaths {
        capture_dir: capture_dir.clone(),
        state_dir: state_dir.clone(),
    });

    // Durable config lives on the real, persistent state dir (survives a
    // reboot), not the /mnt/capture tmpfs it used to — design doc §2.1.
    // A fast tmpfs cache mirrors it for every frequent/polled read.
    let cache_dir = resolve_scheduler_cache_dir();
    let config_path = state_dir.join("config.json");
    let config_cache_path = cache_dir.join("config.json");
    if let Err(error) = durable_state::hydrate_cache(&config_path, &config_cache_path).await {
        warn!(%error, path = %config_path.display(), "failed to hydrate the config cache from its durable copy at startup");
    }

    // Scheduler run state is a separate durable file from config.json on
    // purpose — see design doc §2.1's commit-clobbers-a-pause race note.
    let run_state_path = state_dir.join("schedule_run_state.json");
    let run_state_cache_path = cache_dir.join("schedule_run_state.json");
    if let Err(error) = durable_state::hydrate_cache(&run_state_path, &run_state_cache_path).await {
        warn!(%error, path = %run_state_path.display(), "failed to hydrate the scheduler run-state cache from its durable copy at startup");
    }
    let initial_run_state = match durable_state::read_cached(&run_state_cache_path).await {
        Ok(content) => serde_json::from_str(&content).unwrap_or_default(),
        Err(_) => optic_scheduler::ScheduleRunState::default(),
    };
    info!(?initial_run_state, "scheduler starting");

    // Preview stop/downsample preferences survive a reboot the same way.
    let preview_state_path = state_dir.join("preview_state.json");
    let preview_state_cache_path = cache_dir.join("preview_state.json");
    if let Err(error) =
        durable_state::hydrate_cache(&preview_state_path, &preview_state_cache_path).await
    {
        warn!(%error, path = %preview_state_path.display(), "failed to hydrate the preview state cache from its durable copy at startup");
    }
    let scheduler = optic_scheduler::SchedulerHandle::spawn(
        camera.clone(),
        capture_log.clone(),
        capture_dir.clone(),
        config_cache_path.clone(),
        run_state_path,
        run_state_cache_path,
        initial_run_state,
        capture_dir.join("preview_config.json"),
    );

    // Passive health monitor, daily digest and heartbeat
    // (docs/optic-daemon-alerts.md, docs/optic-daemon-digest-heartbeat.md):
    // reads the handles above, never changes them. Its settings live in
    // config.json's `notifications` section; the legacy alerts.json is
    // imported once.
    let alerts = optic_alerts::AlertsHandle::spawn(
        optic_alerts::load_config(&optic_alerts::resolve_config_path()),
        optic_alerts::AlertSources {
            scheduler: scheduler.clone(),
            sync: sync.clone(),
            capture_log: capture_log.clone(),
            system_status: system_status.clone(),
            config_paths: optic_alerts::ConfigPaths {
                config_path: config_path.clone(),
                config_cache_path: config_cache_path.clone(),
                // Same staging file AppState uses (web.rs AppState::new).
                preview_config_path: capture_dir.join("preview_config.json"),
            },
            events: events.clone(),
            digest_state_path: state_dir.join("digest_state.json"),
            camera_detected: sensor.is_some(),
            version: env!("CARGO_PKG_VERSION"),
        },
    );

    let state = AppState::new(
        camera.clone(),
        sync.clone(),
        capture_log,
        system_status,
        scheduler.clone(),
        capture_dir,
        config_path,
        config_cache_path,
        preview_state_path,
        preview_state_cache_path,
        asset_dir,
        sensor,
    )
    .with_events(events.clone());
    let listener = TcpListener::bind(bind).await?;
    info!(address = %bind, "optic_web listening");

    axum::serve(
        listener,
        web::router(state)
            .merge(web::alerts_router(alerts))
            .merge(web::events_router(events.clone())),
    )
    .with_graceful_shutdown(shutdown_signal(camera, sync, scheduler, events))
    .await?;

    Ok(())
}

/// Resolves the remote host/credentials for `optic_sync`.
/// `OPTIC_SYNC_REMOTE_HOST` is the only required variable — its absence
/// leaves the manager permanently `disabled` (fine for local development,
/// where no capture-transfer receiver exists). `OPTIC_SYNC_ENABLED=false`
/// force-disables it even with a host configured, as an operator escape
/// hatch. Port/user/identity/known-hosts default to the values the existing
/// Phase 6 shell transfer already uses on the Pi
/// (`scripts/setup-phase-06-pi-ram-transfer.sh`), so cutover needs no new
/// provisioning.
fn resolve_sync_config() -> Option<SyncConfig> {
    if env::var("OPTIC_SYNC_ENABLED").ok().as_deref() == Some("false") {
        return None;
    }
    let remote_host = env::var("OPTIC_SYNC_REMOTE_HOST").ok()?;
    let remote_port = env::var("OPTIC_SYNC_REMOTE_PORT")
        .ok()
        .and_then(|value| value.parse().ok())
        .unwrap_or(DEFAULT_SYNC_REMOTE_PORT);
    let remote_user =
        env::var("OPTIC_SYNC_REMOTE_USER").unwrap_or_else(|_| DEFAULT_SYNC_REMOTE_USER.to_owned());
    let identity_file = env::var("OPTIC_SYNC_IDENTITY_FILE")
        .map(PathBuf::from)
        .unwrap_or_else(|_| default_ssh_path("optic_capture_ed25519"));
    let known_hosts_file = env::var("OPTIC_SYNC_KNOWN_HOSTS_FILE")
        .map(PathBuf::from)
        .unwrap_or_else(|_| default_ssh_path("optic_capture_known_hosts"));

    Some(SyncConfig {
        remote_host,
        remote_port,
        remote_user,
        identity_file,
        known_hosts_file,
    })
}

fn default_ssh_path(filename: &str) -> PathBuf {
    let home = env::var("HOME").unwrap_or_else(|_| "/tmp".to_owned());
    PathBuf::from(home).join(".ssh").join(filename)
}

/// Resolves the SQLite history database path for `optic_capture_log`.
/// `OPTIC_CAPTURE_LOG_DB` overrides it explicitly; otherwise it defaults to
/// `~/.local/state/optic-daemon/history.db` — deliberately outside
/// `~/.local/bin/`, which `scripts/setup-optic-daemon-phase-01.sh` wholesale
/// replaces on every deploy (see design doc §3.2).
fn resolve_capture_log_db_path() -> PathBuf {
    if let Ok(configured) = env::var("OPTIC_CAPTURE_LOG_DB") {
        return PathBuf::from(configured);
    }
    let home = env::var("HOME").unwrap_or_else(|_| "/tmp".to_owned());
    PathBuf::from(home)
        .join(".local/state/optic-daemon")
        .join("history.db")
}

/// Resolves the tmpfs directory used as a fast read-through cache mirror
/// of durably-stored config (design doc §2.1). `OPTIC_CACHE_DIR` overrides
/// it explicitly; otherwise defaults to `/dev/shm/optic-daemon` on Linux —
/// a separate tmpfs from the bounded 256 MiB `/mnt/capture` capture queue,
/// so this cache never competes with capture-file storage for space.
/// `/dev/shm` isn't a real, writable path on macOS, so local `cargo run`
/// dev sessions fall back to the system temp dir instead (same rationale
/// as `DEV_ASSET_DIR` above: this project's dev target is macOS, but
/// nothing here should require a Linux-only path to even start).
fn resolve_scheduler_cache_dir() -> PathBuf {
    if let Ok(configured) = env::var("OPTIC_CACHE_DIR") {
        return PathBuf::from(configured);
    }
    #[cfg(target_os = "linux")]
    {
        PathBuf::from("/dev/shm/optic-daemon")
    }
    #[cfg(not(target_os = "linux"))]
    {
        std::env::temp_dir().join("optic-daemon-cache")
    }
}

/// Resolves the directory `index.html`, `app.js`, and `styles.css` are read
/// from on every request. `OPTIC_WEB_ASSETS_DIR` overrides it explicitly;
/// otherwise the daemon looks for a `web` directory installed as a sibling of
/// its own executable (`std::env::current_exe()`), matching the deployment
/// layout that places assets next to `~/.local/bin/optic-daemon`. If neither
/// resolves to a real directory, it falls back to the workspace source tree.
fn resolve_web_asset_dir() -> PathBuf {
    if let Ok(configured) = env::var("OPTIC_WEB_ASSETS_DIR") {
        return PathBuf::from(configured);
    }

    let exe_sibling = env::current_exe()
        .ok()
        .and_then(|exe| exe.parent().map(|dir| dir.join("web")));
    match exe_sibling {
        Some(dir) if dir.is_dir() => dir,
        _ => PathBuf::from(DEV_ASSET_DIR),
    }
}

async fn validate_capture_dir(path: &PathBuf) -> Result<(), Box<dyn std::error::Error>> {
    let metadata = tokio::fs::metadata(path).await?;
    if !metadata.is_dir() {
        return Err(format!("capture path is not a directory: {}", path.display()).into());
    }

    let probe = path.join(format!(".optic-web-write-test-{}", std::process::id()));
    tokio::fs::write(&probe, b"").await?;
    tokio::fs::remove_file(&probe).await?;
    Ok(())
}

async fn shutdown_signal(
    camera: OpticCamera,
    sync: DataSyncManager,
    scheduler: optic_scheduler::SchedulerHandle,
    events: Option<SystemEventLog>,
) {
    #[cfg(unix)]
    {
        let mut terminate =
            tokio::signal::unix::signal(tokio::signal::unix::SignalKind::terminate())
                .expect("SIGTERM handler");
        tokio::select! {
            result = tokio::signal::ctrl_c() => {
                if let Err(error) = result {
                    warn!(%error, "failed to listen for Ctrl-C");
                }
            }
            _ = terminate.recv() => {}
        }
    }

    #[cfg(not(unix))]
    if let Err(error) = tokio::signal::ctrl_c().await {
        warn!(%error, "failed to listen for Ctrl-C");
    }

    info!("shutdown requested");
    // Recorded first: the steps below can hang until systemd SIGKILLs the
    // process, and then nothing after them runs.
    if let Some(events) = &events {
        match optic_events::host_shutdown_action().await {
            Some((kind, target)) => {
                info!(target, "host is going down");
                events
                    .record(kind, serde_json::json!({ "target": target }))
                    .await;
            }
            None => {
                events
                    .record(SystemEventKind::DaemonStop, serde_json::json!({}))
                    .await;
            }
        }
    }
    if let Err(error) = camera.shutdown().await {
        warn!(%error, "failed to shut down optic_camera cleanly");
    }
    if sync.shutdown().await.is_err() {
        warn!("failed to shut down optic_sync cleanly");
    }
    if scheduler.shutdown().await.is_err() {
        warn!("failed to shut down optic_scheduler cleanly");
    }
}

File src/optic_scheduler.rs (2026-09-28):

//! Composable timelapse scheduling (`docs/optic-daemon-scheduler.md`).
//!
//! Two halves: a pure rule-composition engine (data types, the
//! deterministic `occurrences()` function, merge/tag, slug validation —
//! Phase 1a) with no camera/hardware dependency, and a bounded actor
//! (`SchedulerHandle`, Phase 1c) that actually ticks against real time and
//! fires captures, following the same shape as `optic_camera`/`optic_sync`.
//! `occurrences()` is deliberately the single implementation used for both
//! "what should fire next" (the actor) and "what would the next 48h look
//! like" (the design doc's future Shot Forecaster, 1d) — see design doc §3.

use std::{
    collections::HashSet,
    path::PathBuf,
    sync::{Arc, Mutex},
};

use chrono::{DateTime, Datelike, Duration, NaiveTime, Utc, Weekday};
use chrono_tz::Tz;
use serde::{Deserialize, Serialize};
use tokio::sync::{mpsc, oneshot, watch};

use crate::{
    camera::CaptureExposure,
    camera::{AppConfig, CaptureProfile, CaptureRequest, CaptureSource},
    durable_state, ephemeris,
    exposure_ramp::{self, FrameObservation, RampDecision, RampPlan, RampState, ScheduleExposure},
    optic_camera::OpticCamera,
    optic_capture_log::{CaptureLog, CaptureLogEntry},
};

/// Occurrences within this window of each other collapse into one physical
/// capture (design doc §3.1). The doc originally proposed 5s on the
/// assumption real captures are faster than that; measured data
/// (`docs/optic-daemon-capture-performance.md`) shows real captures
/// actually take ~5.1-5.6s end to end, right at that line — 10s gives real
/// margin above the slowest measured profile (MasterArchive+DNG, ~5.46s)
/// so two rules whose occurrences are genuinely close together still merge
/// into one physical shot, not two, per user decision 2026-09-20.
pub const MERGE_WINDOW: Duration = Duration::seconds(10);

#[derive(Debug, Clone, Copy, PartialEq, Eq, Serialize, Deserialize)]
pub enum ScheduleRunState {
    Running,
    Paused,
}

impl Default for ScheduleRunState {
    /// A freshly-provisioned station shouldn't start autonomously firing
    /// captures before an operator has reviewed its rules.
    fn default() -> Self {
        Self::Paused
    }
}

#[derive(Debug, Clone, PartialEq, Serialize, Deserialize)]
#[serde(default, deny_unknown_fields)]
pub struct Station {
    pub latitude: f64,
    pub longitude: f64,
    pub elevation_m: f64,
    /// IANA timezone name (e.g. "America/Vancouver"). Stored explicitly
    /// rather than read from the OS at run time, so the schedule stays
    /// correct/self-describing even if the Pi's system timezone changes.
    pub timezone: String,
}

impl Default for Station {
    fn default() -> Self {
        Self {
            latitude: 0.0,
            longitude: 0.0,
            elevation_m: 0.0,
            timezone: "UTC".to_owned(),
        }
    }
}

impl Station {
    fn tz(&self) -> Tz {
        self.timezone.parse().unwrap_or(chrono_tz::UTC)
    }
}

#[derive(Debug, Clone, Default, PartialEq, Serialize, Deserialize)]
#[serde(default, deny_unknown_fields)]
pub struct ScheduleConfig {
    pub station: Option<Station>,
    pub rules: Vec<Rule>,
    /// How every scheduled capture is exposed — one global mode, not per
    /// rule (`docs/optic-daemon-exposure-ramping.md` §3.1). Defaults to
    /// `Dashboard`, so a config written before this field existed behaves
    /// exactly as before.
    pub exposure: ScheduleExposure,
}

impl ScheduleConfig {
    fn tz(&self) -> Tz {
        self.station.as_ref().map_or(chrono_tz::UTC, Station::tz)
    }
}

#[derive(Debug, Clone, PartialEq, Serialize, Deserialize)]
#[serde(deny_unknown_fields)]
pub struct Rule {
    pub id: String,
    pub label: String,
    pub slug: String,
    pub enabled: bool,
    pub trigger: Trigger,
    #[serde(default)]
    pub constraints: Constraints,
}

#[derive(Debug, Clone, PartialEq, Serialize, Deserialize)]
#[serde(tag = "kind")]
pub enum Trigger {
    Interval {
        every_secs: u64,
        #[serde(default = "default_align_to_wall_clock")]
        align_to_wall_clock: bool,
    },
    RecurringTime {
        days: RecurringDays,
        time: NaiveTime,
    },
    /// Fires at a Solar/Lunar/MilkyWay event, optionally offset — design
    /// doc §2/§14. Requires `ScheduleConfig.station` to be set; a rule
    /// using this trigger with no station configured produces zero
    /// occurrences (same "dead rule" handling as an unsatisfiable
    /// constraint, not an error — see `rule_occurrences`).
    Ephemeris {
        target: CelestialTarget,
        /// Signed offset from the named event, in seconds (e.g. -1800 =
        /// "30 minutes before"). `chrono::Duration` isn't directly
        /// serde-friendly, so this is stored as the same kind of `_secs`
        /// integer every other duration field in this file already uses.
        #[serde(default)]
        offset_secs: i64,
    },
}

fn default_align_to_wall_clock() -> bool {
    true
}

/// Shared by every event taxonomy that can fire on either an upward or
/// downward crossing of a threshold (design doc §2) — no longer
/// solar-specific in practice (used by `SolarEvent::FixedElevation`,
/// `MilkyWayEvent::CoreElevation`), so the name isn't either.
#[derive(Debug, Clone, Copy, PartialEq, Eq, Serialize, Deserialize)]
pub enum CrossingDirection {
    Rising,
    Setting,
    Both,
}

#[derive(Debug, Clone, PartialEq, Serialize, Deserialize)]
#[serde(tag = "type", content = "event")]
pub enum CelestialTarget {
    Solar(SolarEvent),
    Lunar(LunarEvent),
    MilkyWay(MilkyWayEvent),
}

#[derive(Debug, Clone, Copy, PartialEq, Serialize, Deserialize)]
pub enum SolarEvent {
    SolarNoon,
    Nadir,
    Sunrise,
    Sunset,
    CivilDawn,
    CivilDusk,
    NauticalDawn,
    NauticalDusk,
    AstronomicalDawn,
    AstronomicalDusk,
    GoldenHourMorningStart,
    GoldenHourMorningEnd,
    GoldenHourEveningStart,
    GoldenHourEveningEnd,
    BlueHourMorningStart,
    BlueHourMorningEnd,
    BlueHourEveningStart,
    BlueHourEveningEnd,
    FixedElevation {
        degrees: f64,
        direction: CrossingDirection,
    },
}

#[derive(Debug, Clone, Copy, PartialEq, Serialize, Deserialize)]
pub enum LunarEvent {
    Moonrise,
    Moonset,
    LunarTransit,
    LunarAntitransit,
    NewMoon,
    FirstQuarter,
    FullMoon,
    LastQuarter,
}

#[derive(Debug, Clone, Copy, PartialEq, Serialize, Deserialize)]
pub enum MilkyWayEvent {
    CoreRise,
    CoreSet,
    CoreTransit,
    CoreElevation {
        degrees: f64,
        direction: CrossingDirection,
    },
    Orientation {
        azimuth_degrees: f64,
    },
}
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

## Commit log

2026-09-18 Introduce persistent staged sandbox, AEC-Free manual exposure, and unified Biome build constraints
2026-09-18 Serve web assets dynamically from disk, agnostic to filename
    Replace compile-time include_str! embeds with a generic GET /{*asset}
    route that reads any file under a resolved asset directory (env
    override, then a sibling `web/` dir of the running executable, then
    the workspace src/web for local dev) on every request, so editing or
    adding a file takes effect on refresh with no rebuild. Path traversal
    is blocked both lexically (only plain path components accepted) and
    by canonicalizing and re-checking containment after symlinks resolve.
    Wire up the new icon.svg as favicon and header logo, needing no Rust
    change thanks to the agnostic route and extension-based content-type
    lookup.
    Update the d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
    [main.rs]
2026-09-18 Fix null-dereference crash on control input; ship 0.1.8
    elements.settledLatency was left referencing a #settled-latency
    element that commit 629c65a removed from index.html without cleaning
    up app.js, so every control input (select/slider/checkbox) crashed in
    beginMeasurement with "Cannot set properties of null". Removed the
    dead references; kept the underlying stable-frame bookkeeping since it
    still drives activeMeasurements cleanup, just simplified the three
    now-display-free branches into one settled condition.
    Bump to 0.1.8 and redeploy. Also records a header title/font tweak
    made directly during this session and synced straight to the Pi's
    asset directory (no rebuild needed, per the dyna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
2026-09-20 Add timelapse scheduler with rule editor, and fix related sync/UI bugs
    Introduces the scheduler (rules, triggers, constraints, shot forecaster)
    with its rule-editor UI, plus a batch of bugs found and fixed via live
    testing on the Pi + iMac over the course of this work:
    - Constraints modeled as a struct of named optionals (Constraints,
    TimeWindow) instead of Vec<Constraint>, enforcing "at most one of each
    constraint type" at the Rust type level.
    - Scheduler-triggered captures now use a scheduler- filename prefix with
    the firing rule slug(s) embedded, instead of reusing the testshot-
    prefix meant for manual test captures; optic_sync's allowlist widened
    to match.
    - Fixed a data-loss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
    [main.rs, optic_scheduler.rs]
2026-09-21 Add scheduler phase 2 (ephemeris rules, storage forecast, capture history, config page) and Pi 5 case models
    [RaspberryPi5caseV5T-30mm_fan-4mm.stl, RaspberryPi5caseV5T-case_pi5-4mm.stl]
2026-09-21 Add GitHub Actions CI gates (phase 1) and CI/CD plan
    Plan the CI/CD pipeline (docs/optic-daemon-ci-cd.md) and implement
    phase 1: a CI workflow that runs Biome plus fmt/test/clippy/release
    build in a Debian 13 arm64 container with the same pinned Raspberry Pi
    libcamera packages as the Pi build, and uploads the checked binary as
    an artifact. Nothing deploys.
    - rust-toolchain.toml becomes the single Rust version source; the
    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
2026-09-21 CI: trust the RPi archive key from the pinned keyring package
    Debian 13's apt verifier (sqv) rejects raspberrypi.gpg.key because its
    binding signatures use SHA-1 (not accepted since 2026-02-01). The
    raspberrypi-archive-keyring 2025.1+rpt1 package ships the same key
    (CF8A1AF5...7FA3303E) re-signed with SHA-512; fetch it pinned by SHA-256
    and still verify the fingerprint.
2026-09-21 CI negative test: deliberate rustfmt violation (to be reverted)
    [main.rs]
2026-09-21 Revert CI negative test: deliberate rustfmt violation
    AC6 observed: run 35568071487 failed at the cargo fmt step.
    [main.rs]
2026-09-21 Show confirmed NTP sync state and last-sync cue; ship 0.1.30
    - /api/system/status time_sync gains last_synced_at, read from the mtime
    of /run/systemd/timesync/synchronized, which systemd-timesyncd touches
    on every successful sync. NTPSynchronized alone can't show a new sync:
    it stays yes across the restart.
    - Config page: Sync now shows "Sync requested", then "Synchronized with
    the time server at <time>" once last_synced_at moves past its value
    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
2026-09-21 Add in-daemon health alerts with ntfy notifications
    New optic_alerts module watches scheduler, sync, capture history, and
    system signals every 30s and notifies via ntfy (system curl, no new
    crate) on onset, every 6h while active, and on recovery. Conditions:
    captures stalled/overdue/failing, sync backlog, capture tmpfs low, CPU
    temperature, throttling/under-voltage. Pure debounce/condition logic is
    unit-tested with a fake clock; missing or invalid config falls back to
    dry-run. Credential lives in ~/.config/optic-daemon/alerts.json (0600),
    never in git or argv.
    Adds read-only GET /api/alerts, and shared header status pills (Daemon,
    Camera, Alerts) on every page; removes the Scheduler page's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
    [main.rs]
2026-09-21 Add Mac-side timelapse builder (tools/timelapse)
    New standalone crate `optic-timelapse` that turns synced captures in
    ~/Pictures/Optic into timelapse videos, grouped per rule slug and per
    local day or date range. The capture folder is treated as read-only;
    output goes to ~/Movies/Optic Timelapses.
    - Pure, unit-tested filename parsing, rule resolution (sidecar
    triggered_by first), grouping, gap splitting and ffmpeg planning
    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
2026-09-21 CI: add macOS job for tools/timelapse
    tools/timelapse is a separate Cargo workspace, so the root cargo
    commands in rust-arm64 never built or tested it. Add a
    "Timelapse tool (macOS)" job on macos-15 that runs fmt, clippy, the
    tests with Homebrew ffmpeg (OPTIC_REQUIRE_FFMPEG=1 makes the encode
    test fail rather than skip) and a release build.
    ci-changed-scope.sh now also prints timelapse=true|false so the job
    runs only when the tool or the CI definition changes; it fails open
    like docs_only, whose output is unchanged. The job is not required.
    Also list tools/ in CLAUDE.md's repository structure and record the
    zsh `$var:r` pitfall under Environment and Tooling Constraints.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
2026-09-22 Set explicit frame duration limits for still captures
    Still captures inherited the previous live preview's FrameDurationLimits
    (~500 ms/frame after the 2 FPS Master Archive preview), making "Capture &
    transfer" take ~5.4 s. Still requests now set their own limits: as fast as
    the sensor mode allows, with 500 ms headroom for auto exposure and never
    truncating a manual shutter.
    Measured on optic.local: Master Archive + DNG ~5.4 s -> ~2.5 s, 2K Binning
    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
2026-09-22 Show capture latency in the dashboard MEASUREMENT panel
    Adds a Capture card that times Capture & transfer in the browser (click to
    files queued), with a median per profile/DNG combination, and a trace of how
    long the button stays disabled afterwards (frozen-still hold plus preview
    restart).
2026-09-22 Add preview downsample toggle and persistent Stop/Resume preview
    Downsample preview (Master Archive only): 1352x1014 at 8 fps instead of
    full 4056x3040 at 2 fps (~16 vs ~40 Mbit/s). It forces the full-resolution
    sensor mode and lets the ISP scale down: libcamera's default pick for that
    size (1332x990) is a centre crop, and the 2x2 binned mode looked softer.
    Stop/Resume preview: persisted in preview_state.json (durable plus tmpfs
    mirror, like the scheduler run state), so it survives daemon restarts and
    reboots. While stopped, no tab auto-starts the preview, /api/stream/start
    returns 409, and a capture skips the 3 s post-capture hold.
    Adds POST /api/preview and a preview field to /api/status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
    [main.rs]
2026-09-22 Fix post-merge drift: verify.sh Phase 6, stale-binary deploy, 0.1.31, stale docs
    - verify.sh Phase 6 checks optic_sync (unit target + /api/status) instead
    of the retired shell transfer, and FAILs while the retired
    optic-capture-transfer.timer still runs (it deletes every file in
    /mnt/capture).
    - Deploy script extracts source with fresh mtimes (tar -m) and fails if
    the release binary is not newer than a pre-build marker, so a stale
    artifact in the shared CARGO_TARGET_DIR can no longer be installed.
    - Bump to 0.1.31 so main deploys as a distinct version.
    - Correct stale statements across README, docs/, setup.md and worklogs.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
2026-09-22 Run optic-daemon as a system service; add Power menu and system events log
    System service migration (docs/optic-daemon-system-service.md):
    - optic-daemon.service is now a system unit running as liam (video,
    render), ordered after network-online.target and time-sync.target.
    The Pi's RTC has no battery, so this keeps captures and timestamps off
    the stale clock after a power cut. A drop-in bounds
    systemd-time-wait-sync to 90 s so an offline boot still starts.
    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
2026-09-22 Add dashboard focus tools: histogram, focus peaking, draggable loupe
    Browser-side tools on the live preview for setting the manual 6 mm lens:
    a live histogram with shadow/highlight clipping readouts, focus peaking
    (absolute Sobel threshold with a sensitivity slider), and a loupe (160 px
    source crop at 2x, click or drag to move) with a Tenengrad sharpness
    score vs best. Runs on frames app.js already decodes; no Rust, camera or
    API changes, ships via build-deploy --assets.
    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
2026-09-22 Audit Pi services; disable unused ones in Phase 4/6 provisioning
    Read-only audit of every running and enabled system and user unit on
    optic.local (docs/pi-services-audit.md), with verdicts, evidence, commands,
    savings, risks and undo steps.
    Persist the chosen disables so a rebuilt Pi matches:
    - setup-phase-04: disable man-db.timer, udisks2, both apt timers (unless
    APT::Periodic is set), e2scrub units (unless / is on LVM), the global
    mpris-proxy user unit, cron (only if no job needs it), cloud-init (only
    once done), and tty1 autologin (only if liam has a usable password).
    Fix the firmware renderer so the Phase 5 block after it no longer makes
    every rerun rewrite config.txt and ask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
2026-09-22 Add daily digest, ntfy heartbeat, and notification settings in config.json
    - Daily digest at 08:00 Station time: frames captured vs expected (only
    while the scheduler was running), gaps, failures, bytes, sync backlog,
    CPU temperature, free space, alerts, boots, heartbeat, uptime, version.
    - External heartbeat as an ntfy dead-man's switch: re-arms a scheduled
    message every 10 min (delivered 30 min after the last check-in);
    withheld while capture-path alerts are active or the camera is missing;
    cancels the armed message on channel changes; "checking in again" notice.
    - Notification settings move into config.json's `notifications` section
    (alerts.json imported once), edited on the C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
    [main.rs]
2026-09-22 Put notification switches on their heading lines
    Notifications, Daily digest and Heartbeat switches sit beside their
    headings, and the Keep/Remove saved-token selector sits beside the token
    field, so the text fields line up in two columns.
2026-09-22 Show saved secrets masked in their fields; fix Save button state
    Topic and token fields show the saved mask as their value: unchanged
    keeps it, cleared removes it (new clear_topic API flag next to
    clear_token), a new value replaces it. Drops the Keep/Remove control.
    Save is enabled only while the form differs from what was last saved.
2026-09-22 Add exposure ramping (Holy Grail day-to-night) for scheduled captures
    One global exposure mode for all scheduled captures (Dashboard or
    AutoRamp): each captured frame is metered (trimmed log-mean luma), the
    target brightness follows sun elevation (day level to +6 deg, 2 EV darker
    by -18 deg), exposure moves at most 1/3 EV per frame into shutter first
    and gain last, capped by the gap to the next shot, and white balance
    eases via grey-world instead of per-frame AWB. The Scheduler page gets a
    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
2026-09-22 Move scheduled exposure onto the dashboard with a live preview
    A "Scheduled exposure" toggle below Shutter replaces the Scheduler-page
    card. When on, Shutter/Gain/White balance lock and show the next scheduled
    frame's planned exposure (GET /api/status exposure_plan, recomputed per
    poll from the ramp state and the current sun elevation) in amber with a
    pulse on change, and the live preview uses a brightness-equivalent,
    never-staged exposure_override so the result can be checked visually.
    Settings shrink to Night look, Max gain and Max shutter plus Advanced;
    each field stages only itself (fixes the max_step_ev rounding write-back).
    The Scheduler page shows ramp status read-only.
    Design: docs/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
    [optic_scheduler.rs]
2026-09-22 Show live auto exposure while seeding; move Rotation under Transform
    While the ramp is seeding, the locked Shutter/Gain/White balance fields
    show the live preview's own auto-exposure values (the same auto exposure
    the seed frame uses) instead of "Auto (seeding)"; ramped plans still show
    the planned values. Rotation moves into the Transform group.
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2026-09-22 Revert "Preview the ramp's brightness before it has any state"
    This reverts commit 8c4c113f8884649c8c5ca2c12df3fc06cba35a89.
    [optic_scheduler.rs]
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2026-09-22 Meter the preview against the staged config, not the committed one
    The preview-metering task read the committed config, so an unsaved
    AutoRamp edit measured nothing and the live preview ignored it — the exact
    case the feature exists for. It now resolves the staged config first, like
    /api/status does, while scheduled captures keep reading the committed one.
    [main.rs, optic_scheduler.rs]
2026-09-22 Stop preview frames from drifting white balance
    White balance eases up to wb_max_step_pct per frame, which is sized for
    captures about a minute apart. Preview frames arrive up to 8 times a
    second, so once the ramp started learning from them the colour temperature
    visibly wandered within seconds. observe_preview now updates brightness
    only: colour gains are seeded once from the preview's AWB and afterwards
    eased solely by captured frames.
2026-09-22 Take white balance out of the ramp entirely
    "Locked" should mean the operator's own White balance setting, held —
    not a number the camera picked at an arbitrary moment. Scheduled captures
    now use the dashboard's White balance control exactly like a manual
    capture, the field stays editable with the toggle on, and the ramp plans
    exposure only: no colour gains in RampState, RampPlan, the live plan or
    the preview override, and no white-balance setting in the UI.
    Choosing a fixed preset also removes the per-frame AWB flicker the
    original easing was meant to solve; leaving it on Auto keeps per-frame
    AWB, which is the operator's call. The UI note says so.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
    [optic_scheduler.rs]
2026-09-22 Default white balance to Daylight and flag Auto as not recommended
    Per-frame AWB makes consecutive timelapse frames jump in colour, so a
    fixed preset is the right default; a DNG keeps white balance adjustable in
    post regardless. The dropdown now labels Auto "(not recommended)" and
    Daylight is the default for fresh configs and Reset defaults.
    Also drops two leftovers from the removed white-balance ramp: the preview
    override no longer forces AWB on (it was overriding the operator's
    setting), and ExposureOverride.colour_gains is gone since nothing read it.
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2026-09-23 case: replace Pi 5 STLs with the STEP assembly, add README and hardware licence
    The STEP AP214 assembly (four parts: box base, box lid, lens back, lens
    cover) is editable CAD; the removed meshes were a different design and
    could not be modified meaningfully. Adds case/README.md (files, parts,
    what is still missing, ASA print section with TBDs) and CERN-OHL-S v2 for
    the hardware design.
    [RaspberryPi5caseV5T-30mm_fan-4mm.stl, RaspberryPi5caseV5T-case_pi5-4mm.stl, pi-cam-case-assembly.step]
2026-09-24 Exposure ramp: highlight guard with a clipping budget
    At night the ramp metered a trimmed log mean and opened up until the dark
    parts reached the night target, whatever that did to the lamps. On
    2026-09-22 (0.1.31, AutoRamp defaults) night frames clipped 2.65% of
    samples; when room-light reflections went off at 21:16/21:22 the ramp
    opened 2.3 EV and the largest blown area grew ~10x.
    Give clipping a budget instead of protecting highlights: 1% of metered
    samples may clip (emissive lamps should); above that the ramp backs off.
    Active only with the sun below 0 deg. Pulls up to 1 EV per frame after
    two consecutive over-budget frames (a single headlight frame is ignored),
    holds between budget/2 a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
    [optic_scheduler.rs]
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2026-09-25 Shorten the preview blackout during scheduled captures
    User report: preview frame rate should be consistent. At night each
    scheduled capture stopped the preview for 22-25 s (11 warmup frames at a
    ~3.5 s exposure), then the preview restarted with its first frames still
    at the still's exposure (~7 s more at ~0.3 fps).
    Measured on the Pi: new request controls only took effect from frame 5
    (frames 1-4 ran at the previous pipeline's exposure), and frames 6-11 of
    a manual still were copies of frame 5 with colour gains moving < 0.1%.
    - Pipelines pass the same controls their requests carry to
    camera.start(), so both still and preview use their own exposure from
    frame 1 (measured on the Pi).
    -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
2026-09-28 Fix the live preview on iOS Safari: stream content type, canvas rendering, status line
    Three defects found while testing the dashboard on an iPhone over Tailscale:
    - "Preview stream interrupted: Load failed". WebKit handles
    multipart/x-mixed-replace inside its network layer, so the page's fetch()
    of the MJPEG stream received an empty body (0 bytes across six attempts,
    while the Mac received 4.5 MB on the same endpoint). /api/stream/mjpeg now
    accepts ?parser=js and returns the identical bytes as
    application/octet-stream, which WebKit passes through; a plain request
    still returns multipart for direct <img> use.
    - The preview flashed black 2-3 times a second. WebKit blanks an <img>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
2026-09-29 Fix the focus tools, silently disabled by the canvas preview
    onFrame() still read img.naturalWidth, which a <canvas> does not have, so it
    returned on every frame and Histogram, Peaking, Clipping and Loupe all did
    nothing. A regression from PR #19, which replaced the preview <img> with a
    canvas: three call sites moved to the frameWidth/frameHeight helpers, this
    one was missed. Nothing failed loudly, because an early return is also how a
    not-yet-loaded frame is skipped.
    The helpers move into the exported surface so Node tests cover them, with
    cases for canvas-shaped, image-shaped and not-ready sources, plus a Rust test
    pinning that onFrame uses them and that the only naturalWidth reads are th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
2026-09-29 Point Beszel at the Mac's current address and stop the hub binding one IP
    Monitoring had been dead for days. Two faults: the hub's launcher binds the
    LAN address found at startup, so after the Mac's DHCP lease moved
    192.168.0.202 -> 192.168.0.231 it kept a socket on an address the machine no
    longer held while still looking healthy; and the Pi's agent still dialled the
    old address, logging "no route to host" every 10 s into the 16 MiB journal
    and evicting crash evidence.
    Fixed on both hosts (hub now binds 0.0.0.0:8090; agent HUB_URL updated) and
    verified: WebSocket connected, zero errors since. This updates verify.sh's
    expected hub URL, records in setup.md why the hub must not bind a single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
2026-10-08 Remove Beszel monitoring entirely
    User decision: Beszel never caught a real outage and caused repeated
    breakage of its own. Its agent needs a literal hub IP (its static Go
    resolver never issues mDNS), so every DHCP change on the Mac broke it -
    four times - and while broken it logged a failure every 10 s, evicting
    crash evidence from the bounded 16 MiB journal. After today's power-cut
    outage the journal held only two boots.
    Removed the agent from the Pi and the hub from the Mac, and stripped it from
    verify.sh (the whole monitoring section, both expected-value variables, the
    monitoring phase, and Phase 6's capture-stage export check), the Phase 6
    setup script, setup.md and the docs. verify.sh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
